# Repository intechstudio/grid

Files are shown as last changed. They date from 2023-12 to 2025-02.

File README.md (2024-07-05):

# Open-Source Hardware [USE THE PAGE ON MASTER BRANCH!]
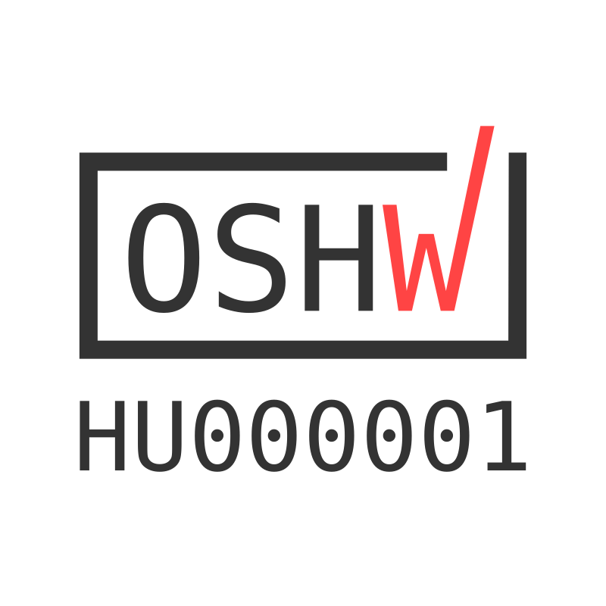
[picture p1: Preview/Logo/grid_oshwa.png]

https://certification.oshwa.org/hu000001.html

Licence: GPL3

# Mechanical components

| Component | Part number | Type | Preview | Links |
|---|---|---|---|---|
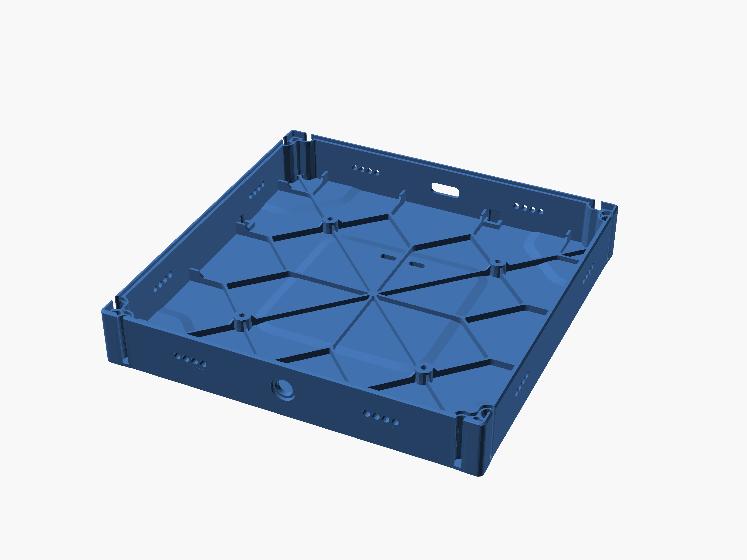
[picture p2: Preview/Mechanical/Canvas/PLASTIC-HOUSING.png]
| Lower housing | PLASTIC-HOUSING | Fabricated |  | [[Model tree]](CANVAS.md) |
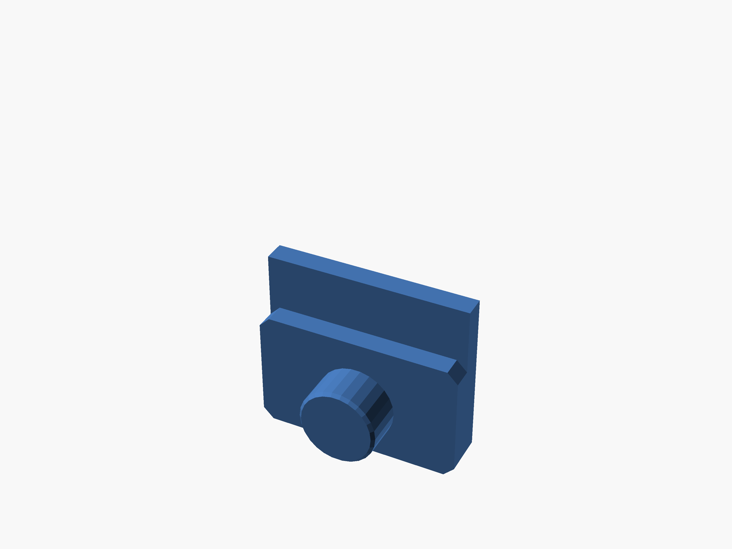
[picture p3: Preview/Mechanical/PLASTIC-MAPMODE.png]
| Mapmode button | PLASTIC-MAPMODE | Fabricated |  | [[step]](Preview/Mechanical/PLASTIC-MAPMODE.step) [[stl]](Preview/Mechanical/PLASTIC-MAPMODE.stl) | 
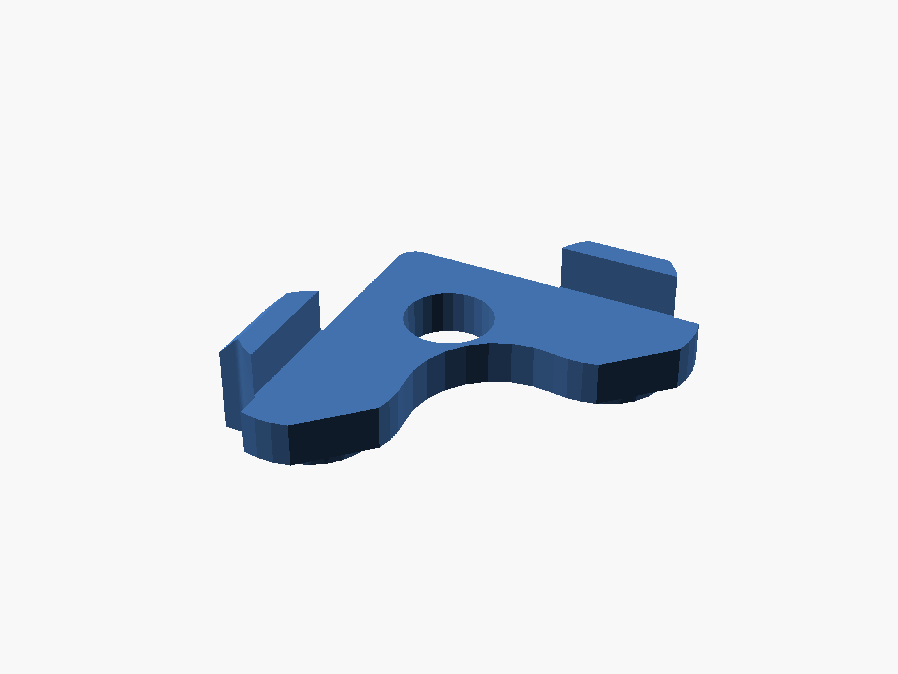
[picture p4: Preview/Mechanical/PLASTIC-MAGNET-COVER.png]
| Magnet cover | PLASTIC-MAGNET-COVER | Fabricated |  | [[step]](Preview/Mechanical/PLASTIC-MAPMODE.step) [[stl]](Preview/Mechanical/PLASTIC-MAGNET-COVER.stl) |  
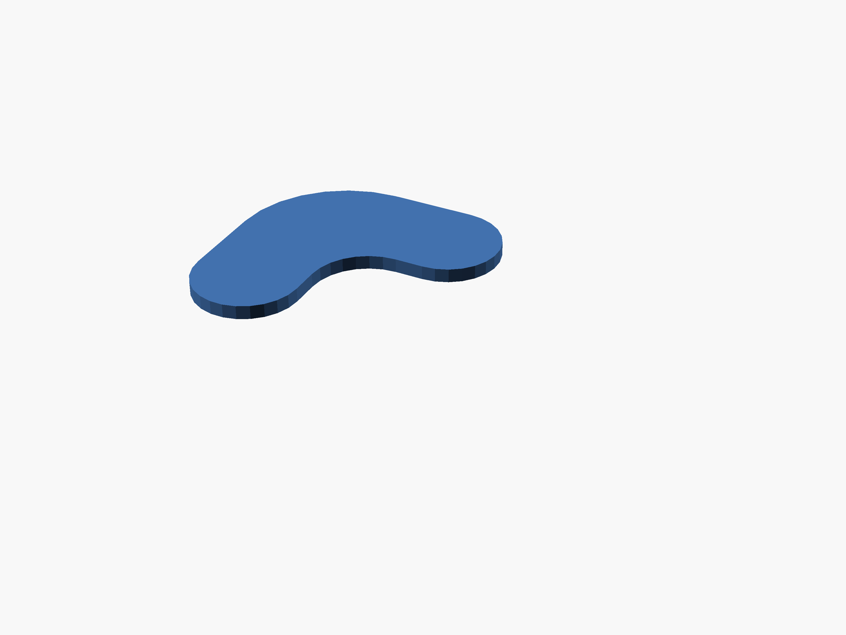
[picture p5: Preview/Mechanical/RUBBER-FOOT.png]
| Rubber foot | RUBBER-FOOT | Fabricated |  | [[step]](Preview/Mechanical/RUBBER-FOOT.step) [[stl]](Preview/Mechanical/RUBBER-FOOT.stl) [[pdf]](Preview/Mechanical/RUBBER-FOOT_Drawing.pdf) |
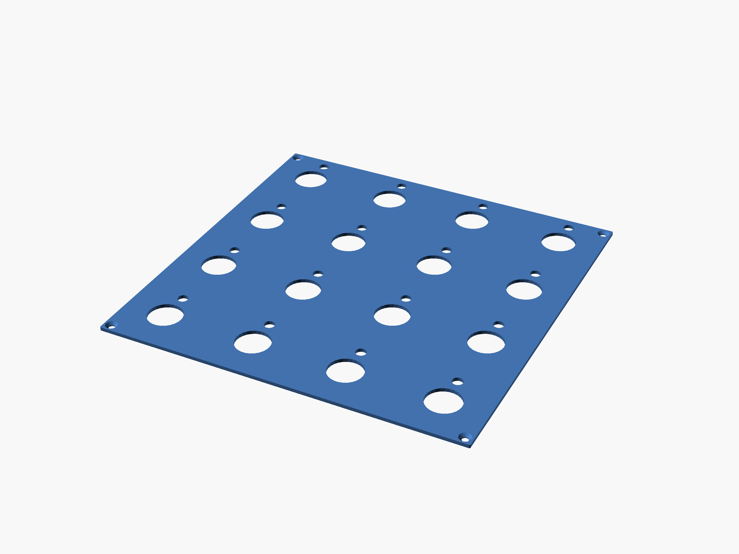
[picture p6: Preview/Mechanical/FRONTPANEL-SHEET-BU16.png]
| Frontpanel BU16 | FRONTPANEL-SHEET-BU16 | Fabricated |  | [[step]](Preview/Mechanical/FRONTPANEL-SHEET-BU16.step) [[stl]](Preview/Mechanical/FRONTPANEL-SHEET-BU16.stl) [[pdf]](Preview/Mechanical/BU16_Drawing.pdf) |
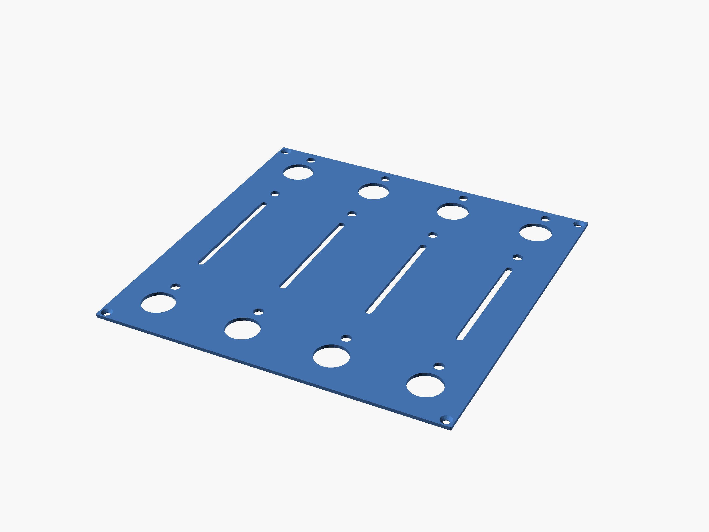
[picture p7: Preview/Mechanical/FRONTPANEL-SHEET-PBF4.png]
| Frontpanel PBF4 | FRONTPANEL-SHEET-PBF4 | Fabricated |  | [[step]](Preview/Mechanical/FRONTPANEL-SHEET-PBF4.step) [[stl]](Preview/Mechanical/FRONTPANEL-SHEET-PBF4.stl) [[pdf]](Preview/Mechanical/PBF4_Drawing.pdf) |
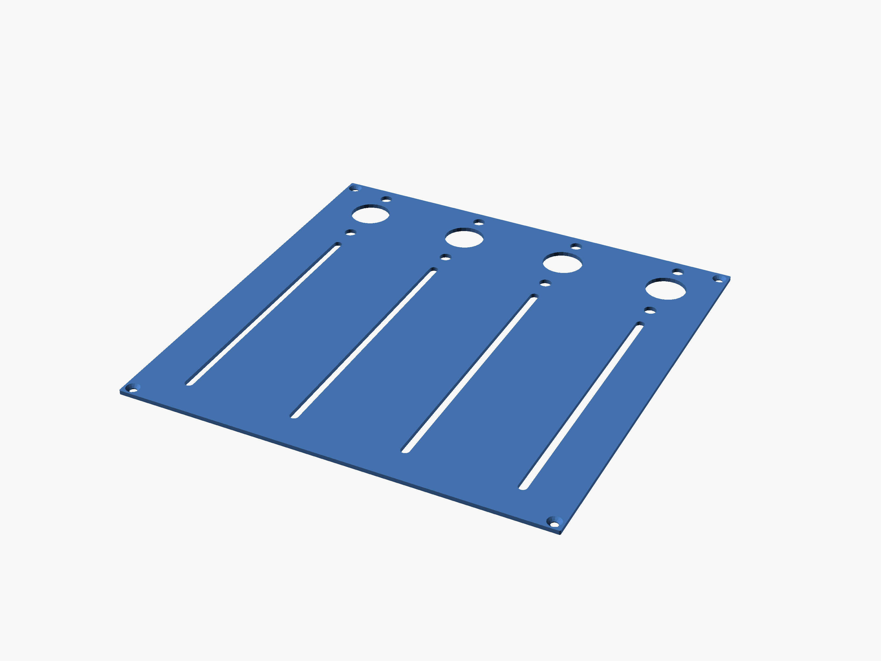
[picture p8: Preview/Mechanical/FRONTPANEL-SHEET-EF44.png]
| Frontpanel EF44 | FRONTPANEL-SHEET-EF44 | Fabricated |  | [[step]](Preview/Mechanical/FRONTPANEL-SHEET-EF44.step) [[stl]](Preview/Mechanical/FRONTPANEL-SHEET-EF44.stl) [[pdf]](Preview/Mechanical/EF44_Drawing.pdf) |
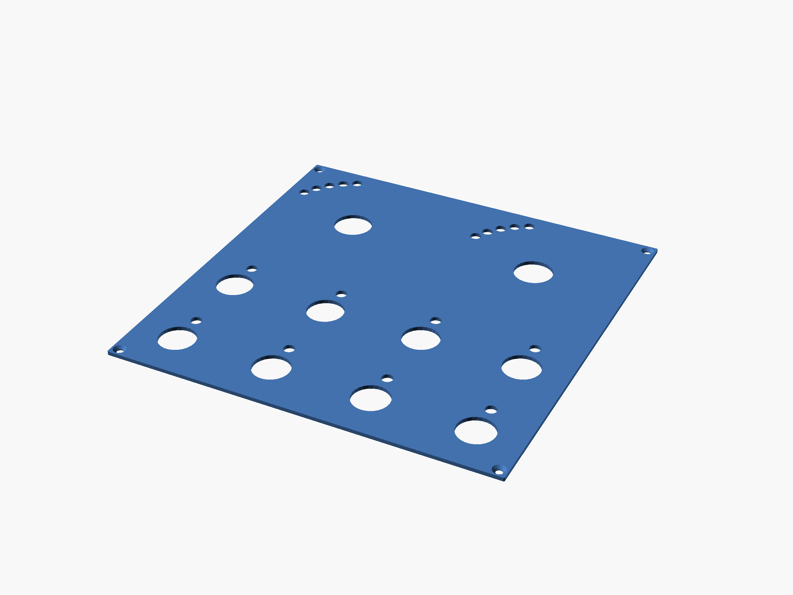
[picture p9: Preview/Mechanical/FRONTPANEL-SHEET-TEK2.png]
| Frontpanel TEK2 | FRONTPANEL-SHEET-TEK2 | Fabricated |  | [[step]](Preview/Mechanical/FRONTPANEL-SHEET-TEK2.step) [[stl]](Preview/Mechanical/FRONTPANEL-SHEET-TEK2.stl) [[pdf]](Preview/Mechanical/TEK2_Drawing.pdf) |
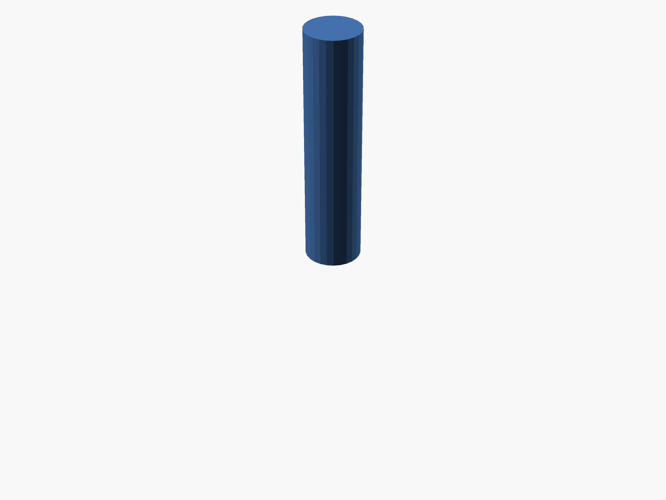
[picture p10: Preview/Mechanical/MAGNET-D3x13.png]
| D3x13mm N52 neodymium | MAGNET-D3x13 | Fabricated |  | [[step]](Preview/Mechanical/MAGNET-D3x13.step) [[stl]](Preview/Mechanical/MAGNET-D3x13.stl) [[pdf]](Preview/Mechanical/MAGNET-D3x13_Drawing.pdf) |
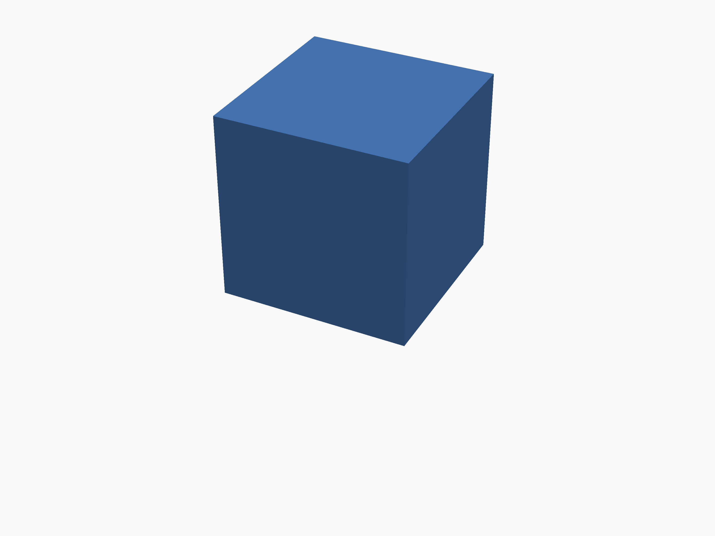
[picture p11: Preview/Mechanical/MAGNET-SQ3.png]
| 3x3x3mm N52 neodymium | MAGNET-SQ3 | Fabricated |  | [[step]](Preview/Mechanical/MAGNET-SQ3.step) [[stl]](Preview/Mechanical/MAGNET-SQ3.stl) [[pdf]](Preview/Mechanical/MAGNET-SQ3_Drawing.pdf) |
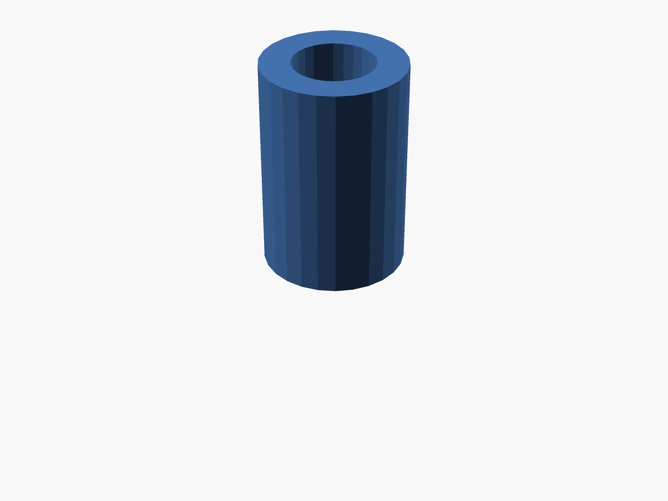
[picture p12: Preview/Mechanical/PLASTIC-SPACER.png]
| Crown | PLASTIC-SPACER | Fabricated |  | [[step]](Preview/Mechanical/PLASTIC-SPACER.step) [[stl]](Preview/Mechanical/PLASTIC-SPACER.stl) [[pdf]](Preview/Mechanical/PLASTIC-SPACER_Drawing.pdf) |
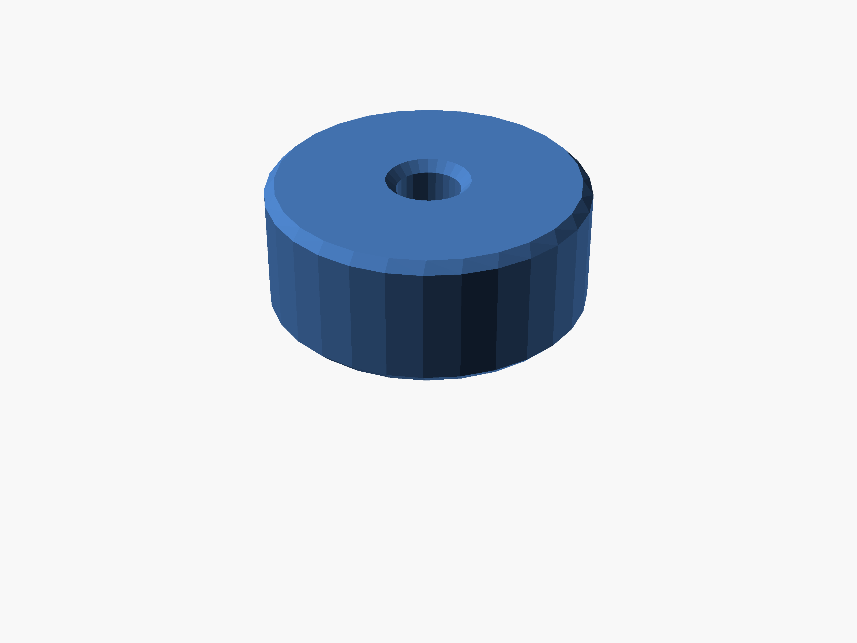
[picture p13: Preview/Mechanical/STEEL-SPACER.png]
| Crown | STEEL-SPACER | Fabricated |  | [[step]](Preview/Mechanical/STEEL-SPACER.step) [[stl]](Preview/Mechanical/STEEL-SPACER.stl) [[pdf]](Preview/Mechanical/STEEL-SPACER_Drawing.pdf) |
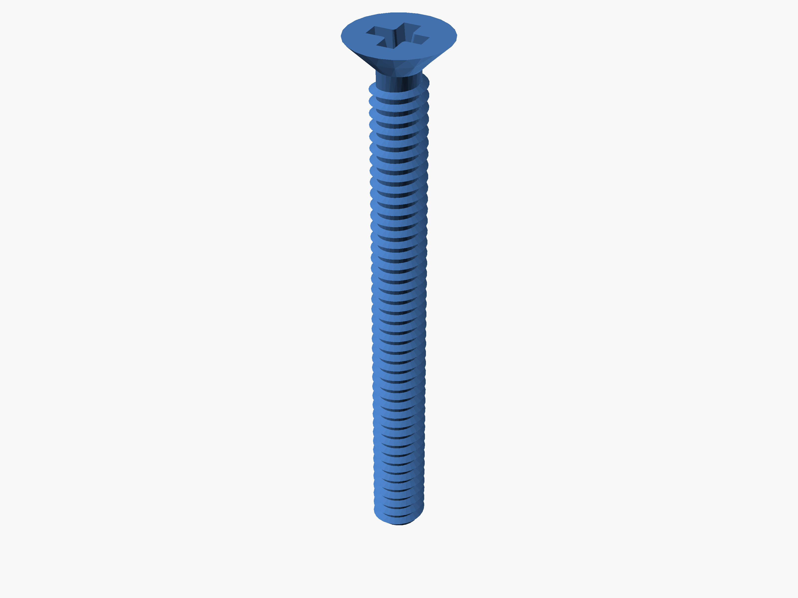
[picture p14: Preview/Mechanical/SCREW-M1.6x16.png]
| Metric corner screw | SCREW-M1.6x16 | Purchased  |  | [[step]](Preview/Mechanical/SCREW-M1.6x16.step) [[stl]](Preview/Mechanical/SCREW-M1.6x16.stl) |
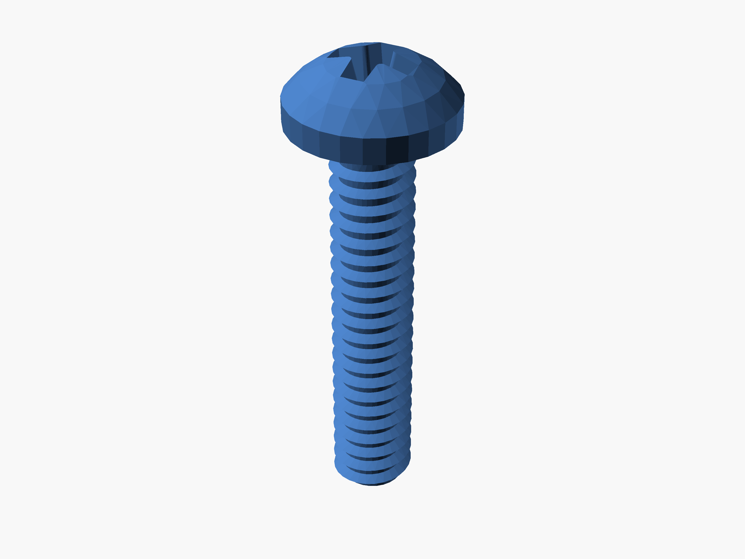
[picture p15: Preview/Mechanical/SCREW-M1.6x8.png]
| Metric PCB screw | SCREW-M1.6x8 | Purchased  |  | [[step]](Preview/Mechanical/SCREW-M1.6x8.step) [[stl]](Preview/Mechanical/SCREW-M1.6x8.stl)|
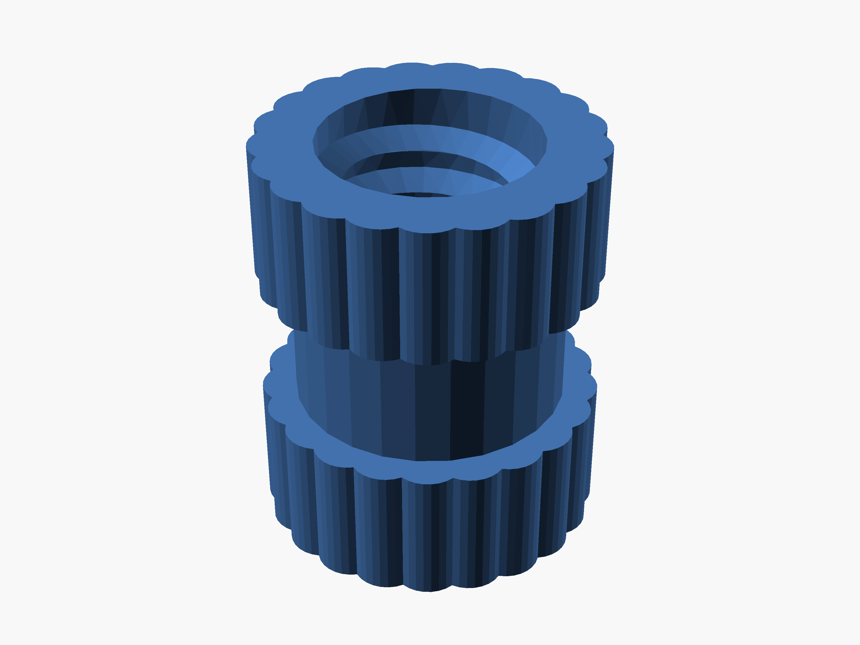
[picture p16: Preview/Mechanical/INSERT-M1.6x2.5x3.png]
| Brass threaded insert 3mm | INSERT-M1.6x2.5x3 | Purchased  |  | [[step]](Preview/Mechanical/INSERT-M1.6x2.5x3.step) [[stl]](Preview/Mechanical/INSERT-M1.6x2.5x3.stl) |
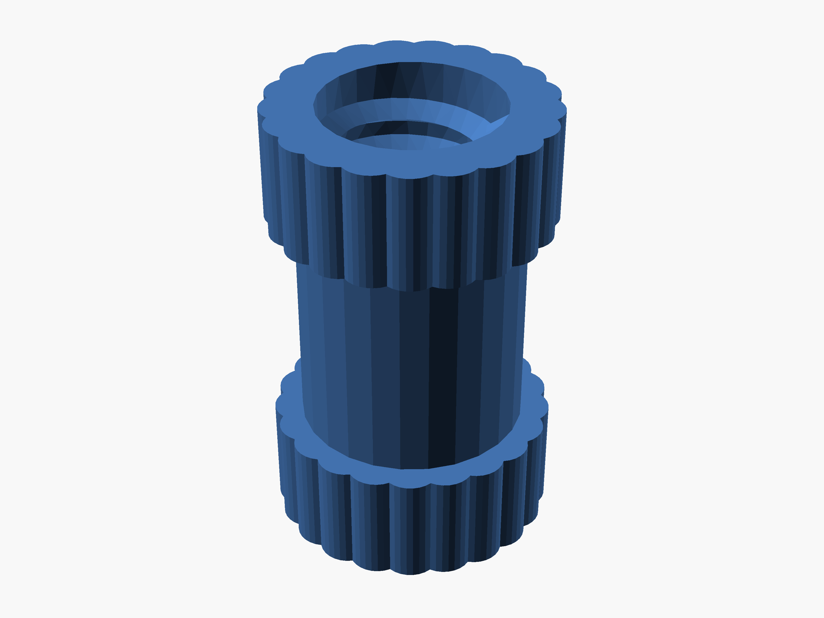
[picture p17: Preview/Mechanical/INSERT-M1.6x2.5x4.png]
| Brass threaded insert 4mm | INSERT-M1.6x2.5x4 | Purchased  |  | [[step]](Preview/Mechanical/INSERT-M1.6x2.5x4.step) [[stl]](Preview/Mechanical/INSERT-M1.6x2.5x4.stl) |
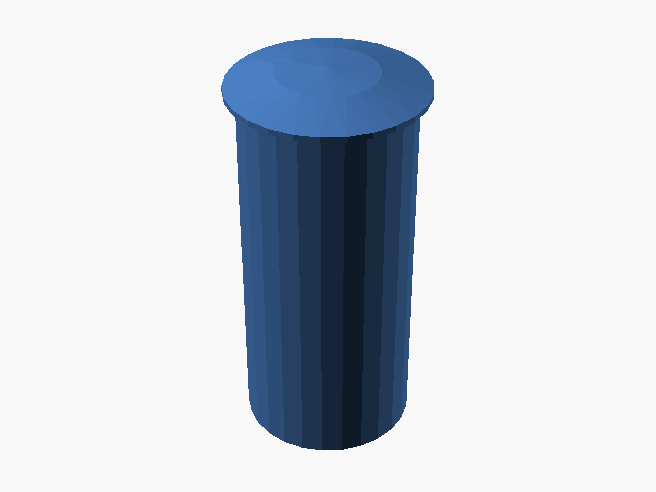
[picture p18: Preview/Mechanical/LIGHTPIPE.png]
| Lightpipe | PLASTIC-LIGHTPIPE | Purchased  |  | [[step]](Preview/Mechanical/LIGHTPIPE.step) [[stl]](Preview/Mechanical/LIGHTPIPE.stl)  |
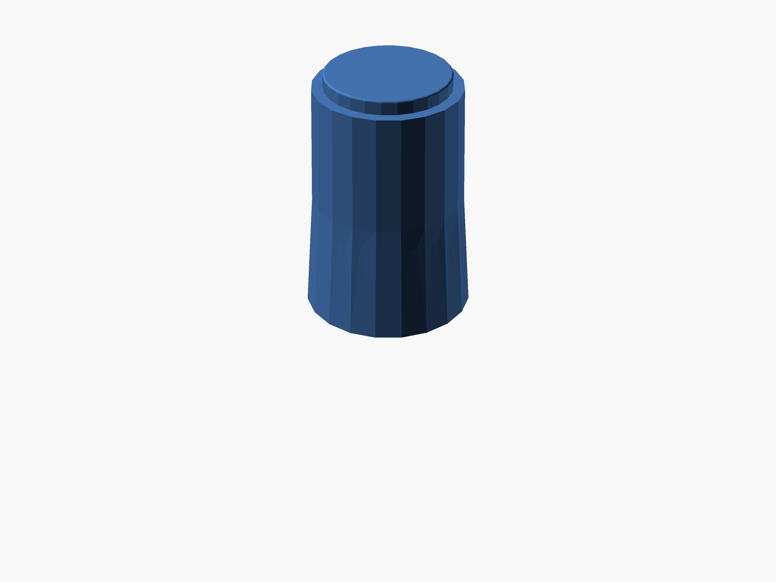
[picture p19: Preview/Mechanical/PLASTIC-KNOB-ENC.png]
| Encoder Knob Injection | PLASTIC-KNOB-ENC | Fabricated |  | [[step]](Preview/Mechanical/PLASTIC-KNOB-ENC.step) [[stl]](Preview/Mechanical/PLASTIC-KNOB-ENC.stl) [[pdf]](Preview/Mechanical/PLASTIC-KNOB-ENC_Drawing.pdf) |
| Potmeter Knob Injection | PLASTIC-KNOB-POT | Fabricated |  | [[step]](Preview/Mechanical/PLASTIC-KNOB-POT.step) [[stl]](Preview/Mechanical/PLASTIC-KNOB-POT.stl) [[pdf]](Preview/Mechanical/PLASTIC-KNOB-POT_Drawing.pdf) |
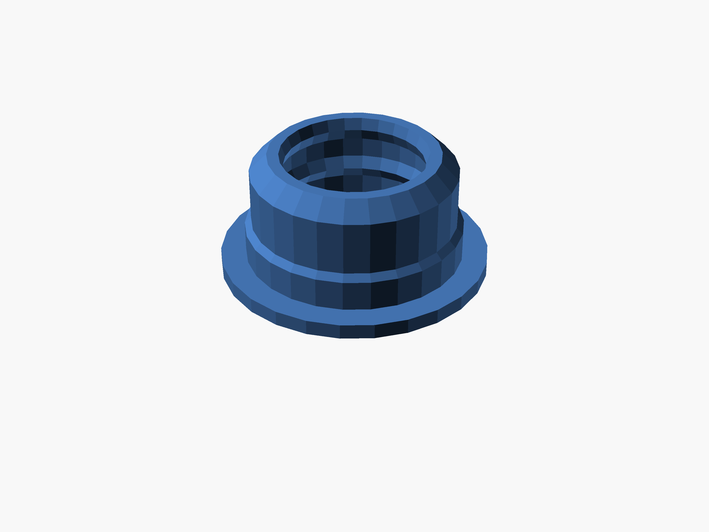
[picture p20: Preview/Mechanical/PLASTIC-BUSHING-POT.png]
| Potmeter Bushing | PLASTIC-BUSHING-POT  | Fabricated |  | [[step]](Preview/Mechanical/PLASTIC-BUSHING-POT.step) [[stl]](Preview/Mechanical/PLASTIC-BUSHING-POT.stl) [[pdf]](Preview/Mechanical/PLASTIC-BUSHING-POT_Drawing.pdf) |
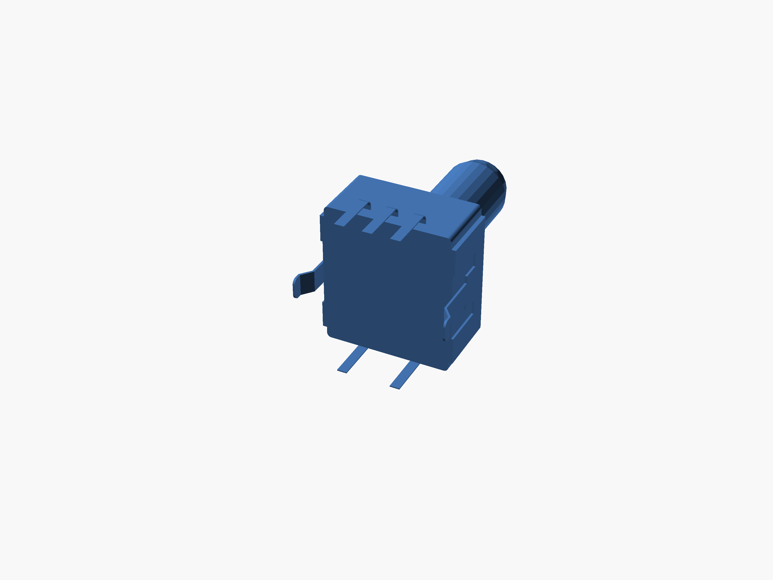
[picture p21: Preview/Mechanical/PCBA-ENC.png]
| Encoder | PCBA-ENC | Purchased  |  | [[step]](Preview/Mechanical/PCBA-ENC.step) [[stl]](Preview/Mechanical/PCBA-ENC.stl) [[pdf]](Preview/Mechanical/PCBA-ENC.pdf) |
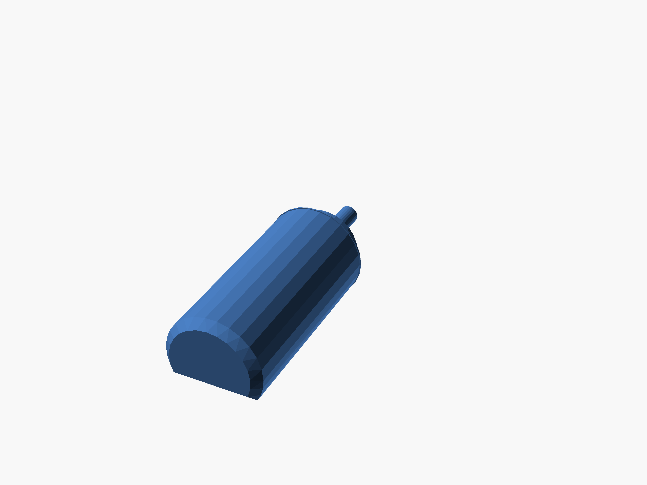
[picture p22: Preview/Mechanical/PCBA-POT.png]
| Potmeter | PCBA-POT | Purchased  |  | [[step]](Preview/Mechanical/PCBA-POT.step) [[stl]](Preview/Mechanical/PCBA-POT.stl) [[pdf]](Preview/Mechanical/PCBA-POT.pdf) |
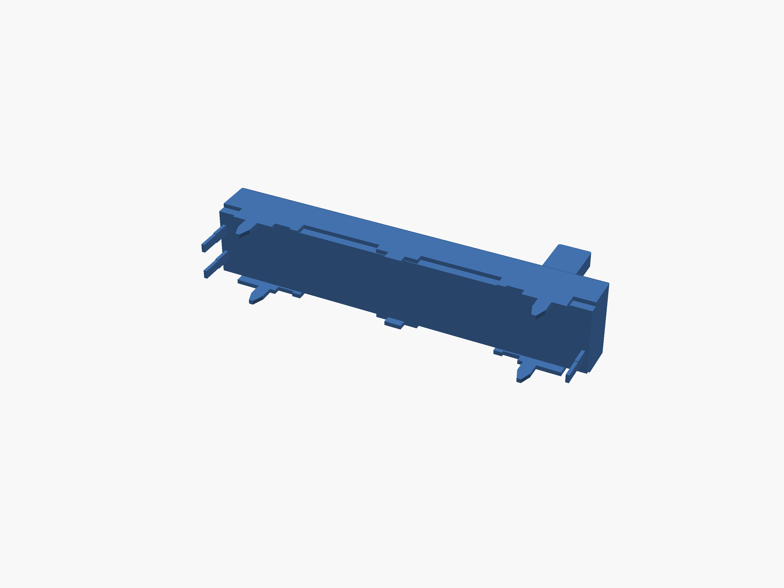
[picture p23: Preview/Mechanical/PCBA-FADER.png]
| Fader | PCBA-FADER | Purchased  |  | [[step]](Preview/Mechanical/PCBA-FADER.step) [[stl]](Preview/Mechanical/PCBA-FADER.stl) [[pdf]](Preview/Mechanical/PCBA-FADER.pdf) |
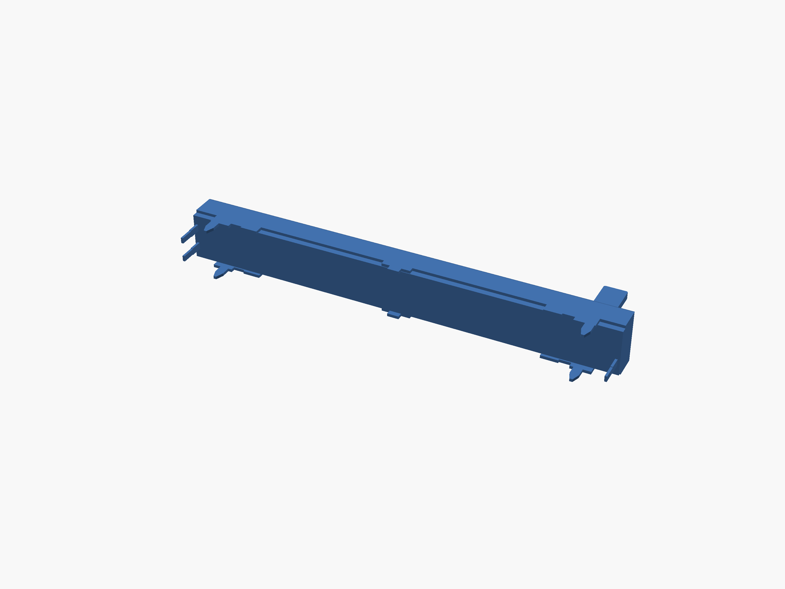
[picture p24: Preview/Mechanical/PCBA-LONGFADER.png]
| Long Fader | PCBA-LONGFADER | Purchased  |  | [[step]](Preview/Mechanical/PCBA-LONGFADER.step) [[stl]](Preview/Mechanical/PCBA-LONGFADER.stl) [[pdf]](Preview/Mechanical/PCBA-LONGFADER.pdf) |
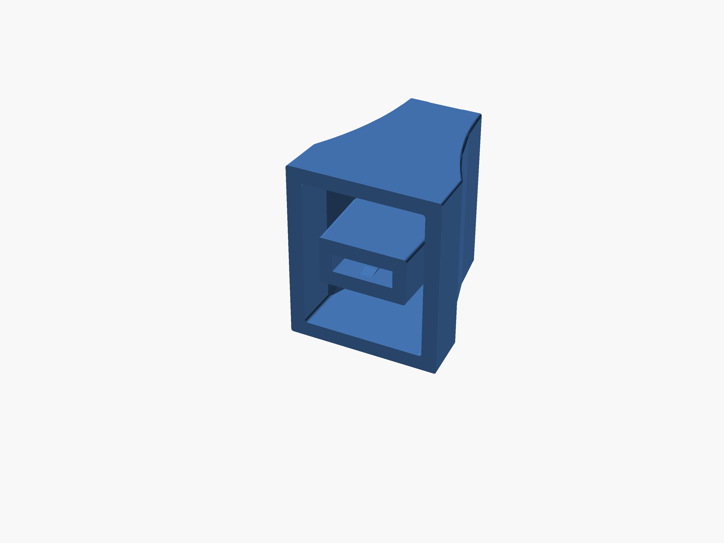
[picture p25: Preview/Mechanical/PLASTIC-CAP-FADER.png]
| Fader Cap | PLASTIC-CAP-FADER | Purchased  |  | [[step]](Preview/Mechanical/PLASTIC-CAP-FADER.step) [[stl]](Preview/Mechanical/PLASTIC-CAP-FADER.stl) |
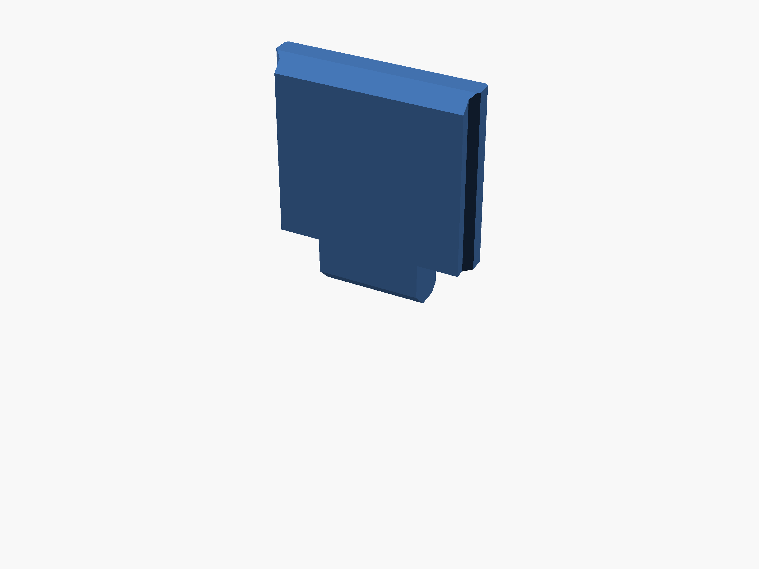
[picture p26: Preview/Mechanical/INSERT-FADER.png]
| Fader Insert | INSERT-FADER | Fabricated  |  | [[step]](Preview/Mechanical/INSERT-FADER.step) [[stl]](Preview/Mechanical/INSERT-FADER.stl) |
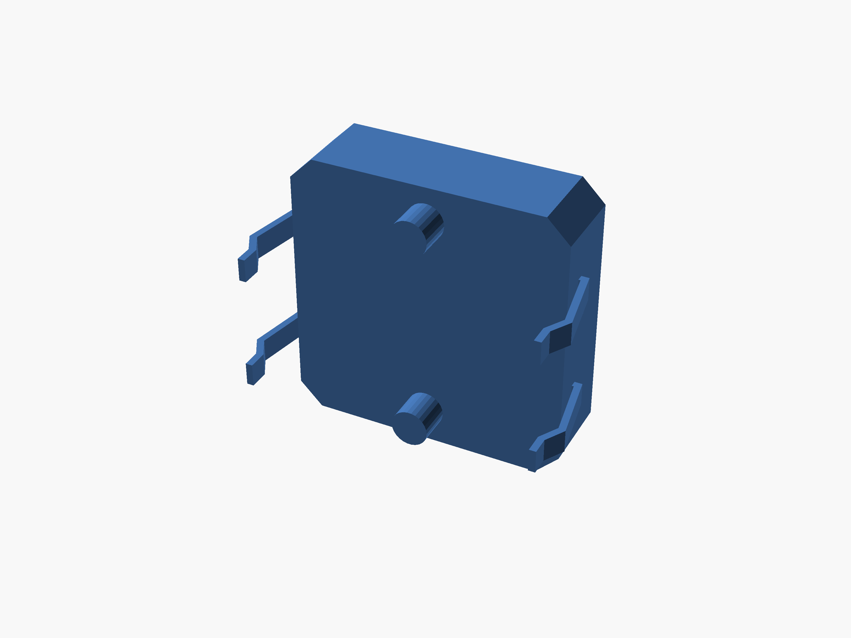
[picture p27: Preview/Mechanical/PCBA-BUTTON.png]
| Button | PCBA-BUTTON | Purchased  |  | [[step]](Preview/Mechanical/PCBA-BUTTON.step) [[stl]](Preview/Mechanical/PCBA-BUTTON.stl) |
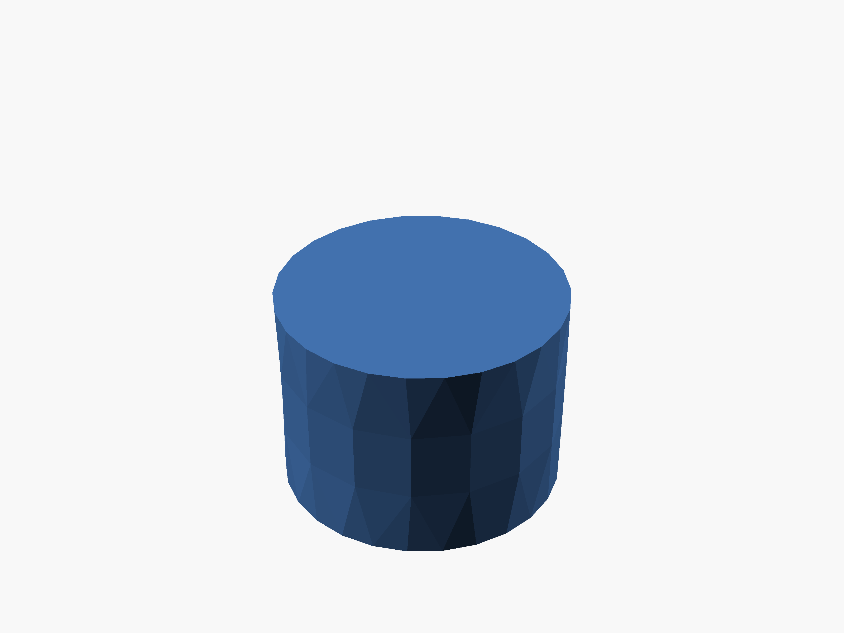
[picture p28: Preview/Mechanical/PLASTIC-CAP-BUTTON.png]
| Button Cap | PLASTIC-CAP-BUTTON | Purchased  |  | [[step]](Preview/Mechanical/PLASTIC-CAP-BUTTON.step) [[stl]](Preview/Mechanical/PLASTIC-CAP-BUTTON.stl) |

# TEK2 specific components
| Component | Part number | Type | Preview | Links |
|---|---|---|---|---|
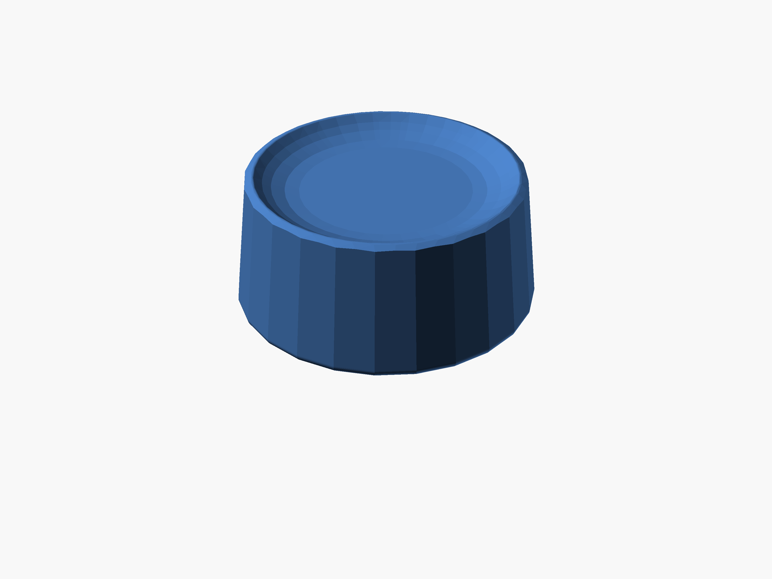
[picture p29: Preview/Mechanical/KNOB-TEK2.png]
| Knob TEK2 | KNOB-TEK2 | Fabricated |  | [[step]](Preview/Mechanical/KNOB-TEK2.step) [[stl]](Preview/Mechanical/KNOB-TEK2.stl) [[pdf]](Preview/Mechanical/KNOB-TEK2_Drawing.pdf) |
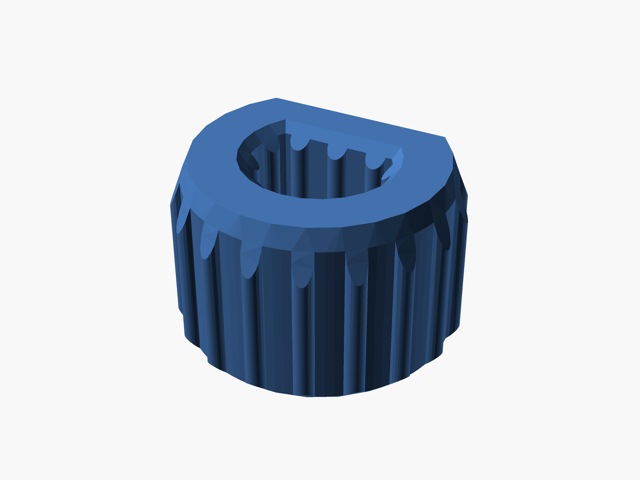
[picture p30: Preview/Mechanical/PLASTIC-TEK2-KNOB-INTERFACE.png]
| Knob interface TEK2 | PLASTIC-TEK2-KNOB-INTERFACE | Fabricated |  | [[step]](Preview/Mechanical/PLASTIC-TEK2-KNOB-INTERFACE.step) [[stl]](Preview/Mechanical/PLASTIC-TEK2-KNOB-INTERFACE.stl) |
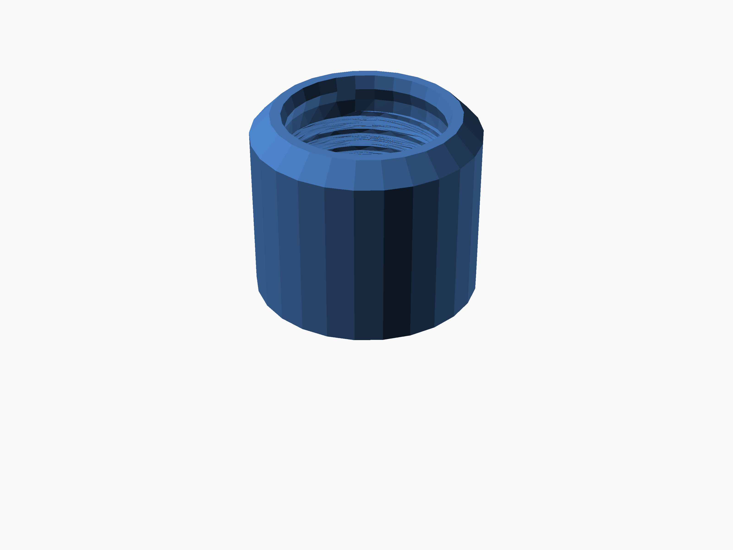
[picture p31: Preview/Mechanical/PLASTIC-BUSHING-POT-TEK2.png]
| Potmeter Bushing TEK2 | PLASTIC-BUSHING-POT-TEK2 | Fabricated |  | [[step]](Preview/Mechanical/PLASTIC-BUSHING-POT-TEK2.step) [[stl]](Preview/Mechanical/PLASTIC-BUSHING-POT-TEK2.stl) [[pdf]](Preview/Mechanical/PLASTIC-BUSHING-POT-TEK2_Drawing.pdf) |
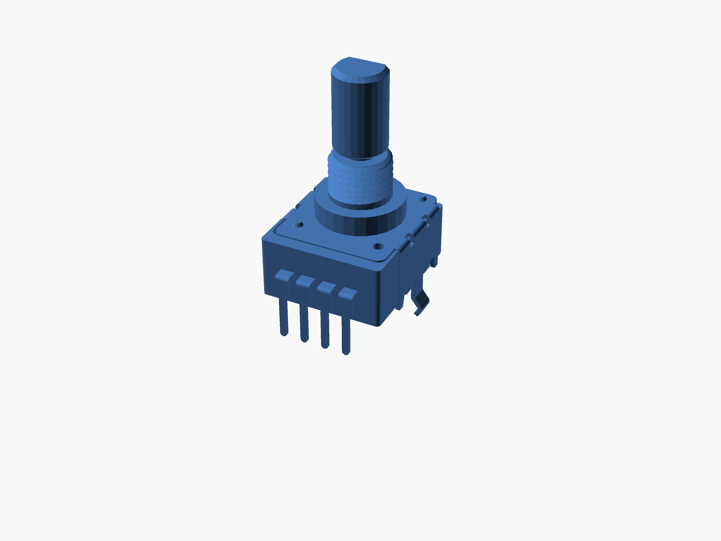
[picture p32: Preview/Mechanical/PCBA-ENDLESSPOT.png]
| Endless potentiometer | PCBA-ENDLESSPOT | Purchased  |  | [[step]](Preview/Mechanical/PCBA-ENDLESSPOT.step) [[stl]](Preview/Mechanical/PCBA-ENDLESSPOT.stl) [[pdf]](Preview/Mechanical/PCBA-ENDLESSPOT.pdf) |
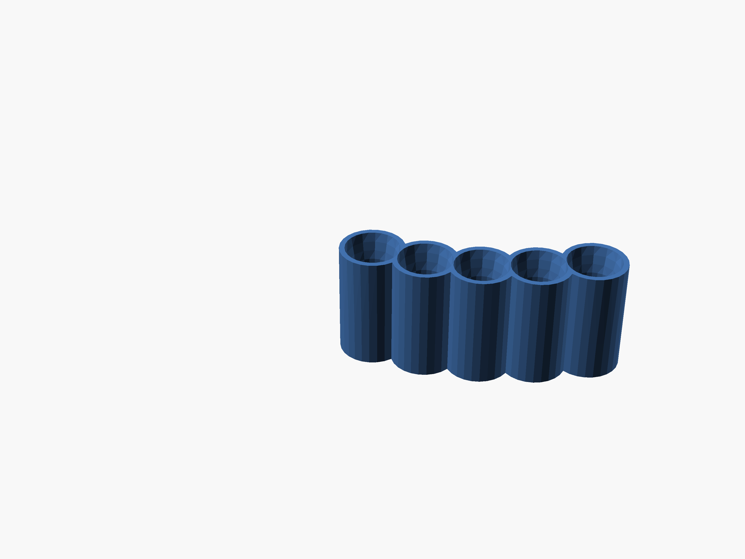
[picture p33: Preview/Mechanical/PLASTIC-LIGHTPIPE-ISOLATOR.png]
| TEK2 Lightpipe isolator | PLASTIC-LIGHTPIPE-ISOLATOR | Fabricated |  | [[step]](Preview/Mechanical/PLASTIC-LIGHTPIPE-ISOLATOR.step) [[stl]](Preview/Mechanical/PLASTIC-LIGHTPIPE-ISOLATOR.stl) |

# TEK1 specific components
| Component | Part number | Type | Preview | Links |
|---|---|---|---|---|
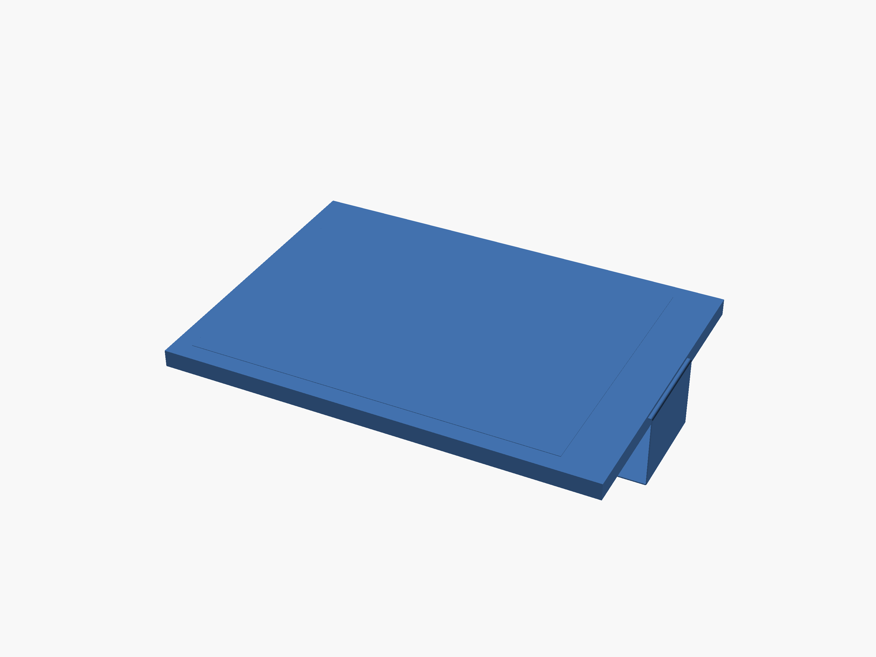
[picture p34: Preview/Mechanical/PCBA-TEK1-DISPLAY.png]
| TEK1 Display | PCBA-TEK1-DISPLAY | Purchased |  | [[step]](Preview/Mechanical/PCBA-TEK1-DISPLAY.step) [[stl]](Preview/Mechanical/PCBA-TEK1-DISPLAY.stl) |
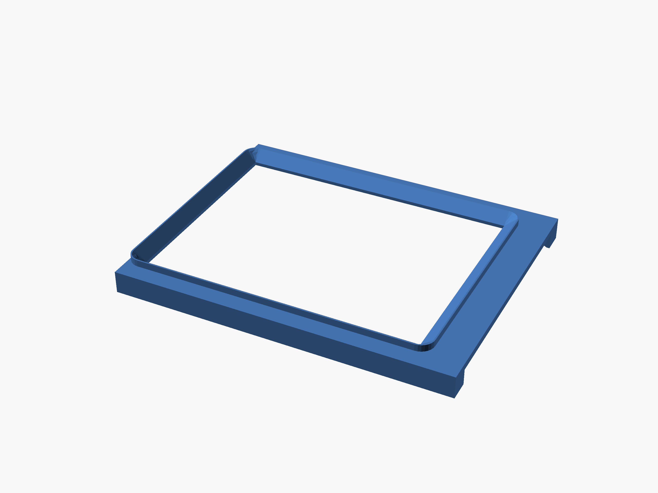
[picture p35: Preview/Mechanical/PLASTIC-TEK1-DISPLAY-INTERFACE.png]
| TEK1 Display interface | PLASTIC-TEK1-DISPLAY-INTERFACE | Fabricated |  | [[step]](Preview/Mechanical/PLASTIC-TEK1-DISPLAY-INTERFACE.step) [[stl]](Preview/Mechanical/PLASTIC-TEK1-DISPLAY-INTERFACE.stl) |
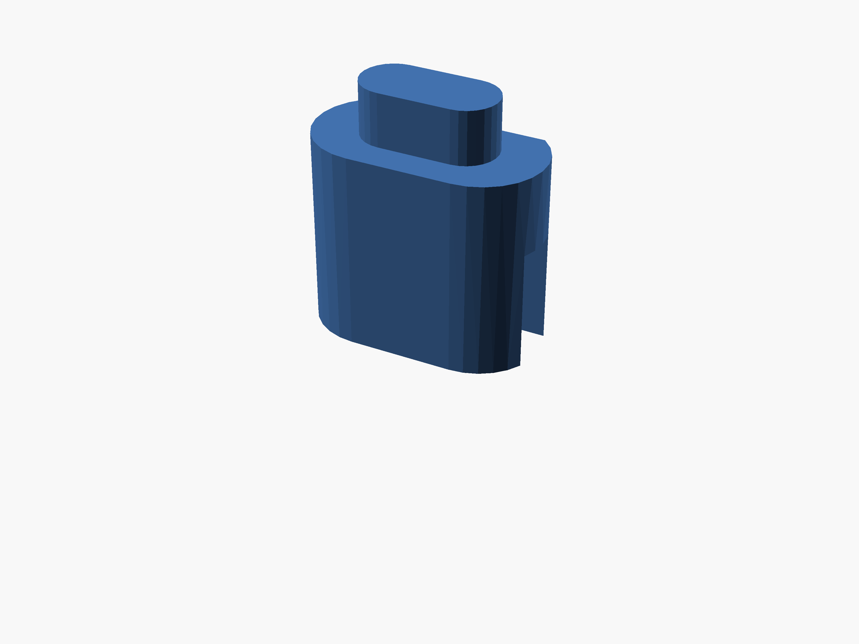
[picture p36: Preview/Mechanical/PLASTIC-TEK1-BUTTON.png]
| TEK1 Button | PLASTIC-TEK1-BUTTON | Fabricated |  | [[step]](Preview/Mechanical/PLASTIC-TEK1-BUTTON.step) [[stl]](Preview/Mechanical/PLASTIC-TEK1-BUTTON.stl) |

## Electrical components

| Component | Part number | Preview | Links |
|---|---|---|---|
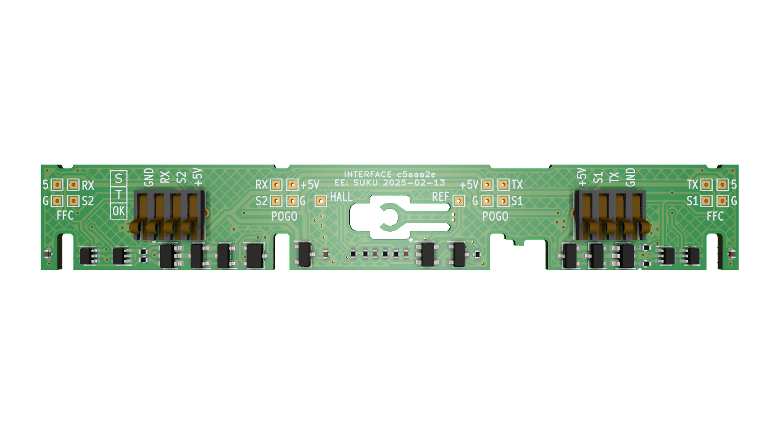
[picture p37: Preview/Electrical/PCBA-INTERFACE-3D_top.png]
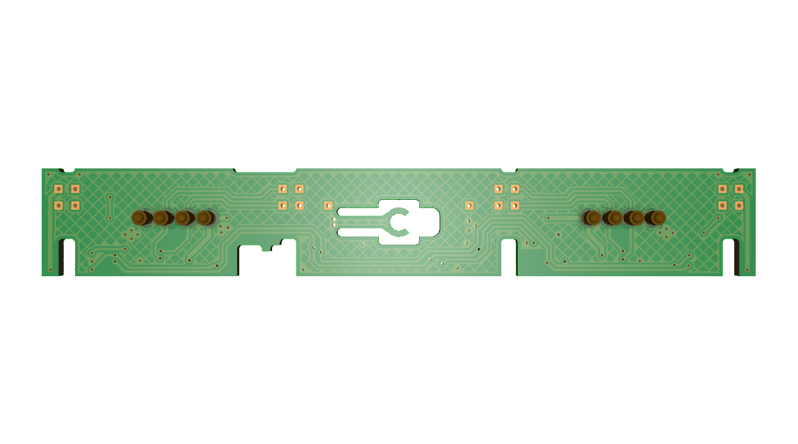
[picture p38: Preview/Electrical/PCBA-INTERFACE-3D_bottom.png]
| Interfaceboard | PCBA-INTERFACE |   | [[Schematic]](Preview/Electrical/PCBA-INTERFACE_Schematic.pdf) [[STEP]](Preview/Electrical/PCBA-INTERFACE-3D.step?raw=true) [[Gerber]](Preview/Electrical/mfg/PCBA-INTERFACE-gerber.zip?raw=true)  [[PCB3D]](Preview/Electrical/PCBA-INTERFACE-blender_export.pcb3d?raw=true)  |
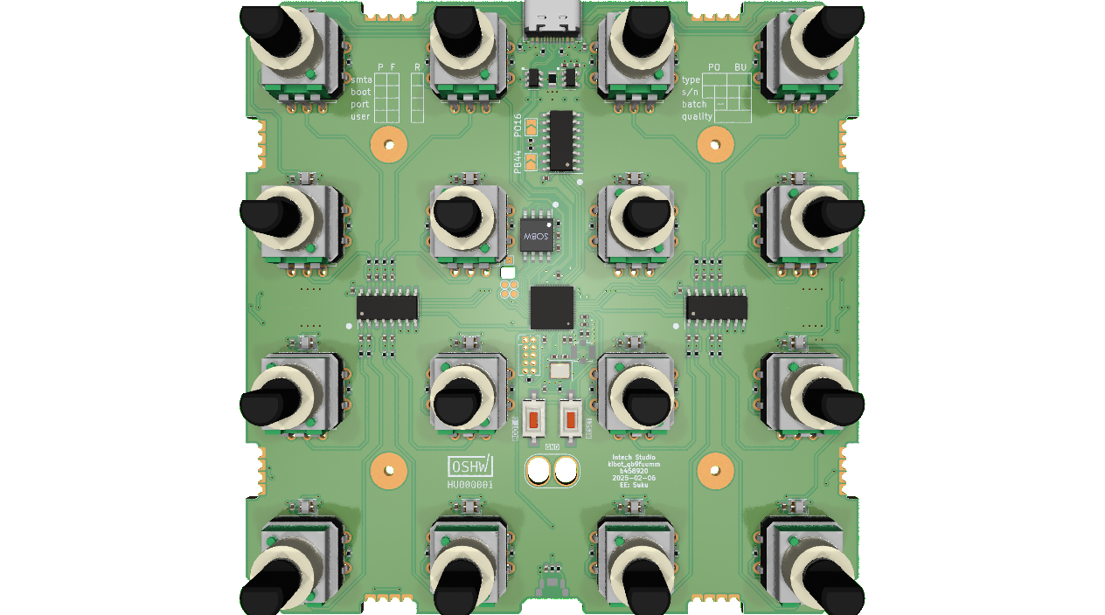
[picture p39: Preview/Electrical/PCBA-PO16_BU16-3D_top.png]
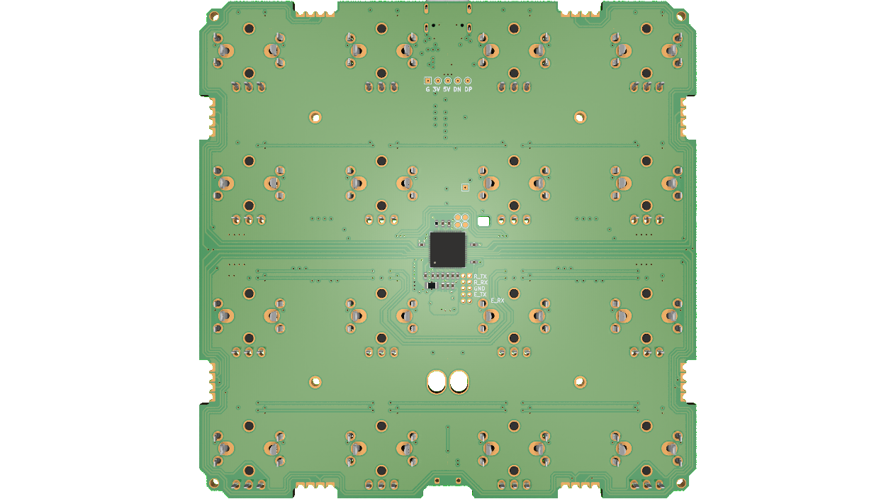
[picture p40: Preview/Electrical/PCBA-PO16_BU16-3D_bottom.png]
| PO16/BU16 Motherboard | PCBA-PO16_BU16 |    | [[schematic]](Preview/Electrical/PCBA-PO16_BU16_Schematic.pdf) [[STEP]](Preview/Electrical/PCBA-PO16_BU16-3D.step?raw=true)  [[PCB3D]](Preview/Electrical/PCBA-PO16_BU16-blender_export.pcb3d?raw=true)  |
| PBF4 Motherboard | PCBA-PBF4 |    | [[schematic]](Preview/Electrical/PCBA-PBF4_Schematic.pdf) [[STEP]](Preview/Electrical/PCBA-PBF4-3D.step?raw=true) [[PCB3D]](Preview/Electrical/PCBA-PBF4-blender_export.pcb3d?raw=true)  |
| EN16 Motherboard | PCBA-EN16 |    | [[schematic]](Preview/Electrical/PCBA-EN16_Schematic.pdf) [[STEP]](Preview/Electrical/PCBA-EN16-3D.step?raw=true) [[PCB3D]](Preview/Electrical/PCBA-EN16-blender_export.pcb3d?raw=true) |
| EF44 Motherboard | PCBA-EF44 |    | [[schematic]](Preview/Electrical/PCBA-EF44_Schematic.pdf) [[STEP]](Preview/Electrical/PCBA-EF44-3D.step?raw=true) [[PCB3D]](Preview/Electrical/PCBA-EF44-blender_export.pcb3d?raw=true) |
| TEK2 Motherboard | PCBA-TEK2 |    | [[schematic]](Preview/Electrical/PCBA-TEK2_Schematic.pdf) [[STEP]](Preview/Electrical/PCBA-TEK2-3D.step?raw=true) [[PCB3D]](Preview/Electrical/PCBA-TEK2-blender_export.pcb3d?raw=true) |
| TEK1 Motherboard | PCBA-TEK1 |    | [[schematic]](Preview/Electrical/PCBA-TEK1_Schematic.pdf) [[STEP]](Preview/Electrical/PCBA-TEK1-3D.step?raw=true) [[PCB3D]](Preview/Electrical/PCBA-TEK1-blender_export.pcb3d?raw=true) |
| TEK1 BNT GROUP | PCBA-TEK1-BTNGROUP |    | [[schematic]](Preview/Electrical/PCBA-TEK1-BTNGROUP_Schematic.pdf) [[STEP]](Preview/Electrical/PCBA-TEK1-BTNGROUP-3D.step?raw=true) [[PCB3D]](Preview/Electrical/PCBA-TEK1-BTNGROUP-blender_export.pcb3d?raw=true) |

# Desktop Tools Used
- FreeCAD
- KiCAD
# Command-Line Tools Used
- PytonOCC
- OpenSCAD
- KiBOT

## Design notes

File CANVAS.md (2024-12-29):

## PLASTIC-HOUSING
Lower plastic casing of the project (internally codenamed Canvas)
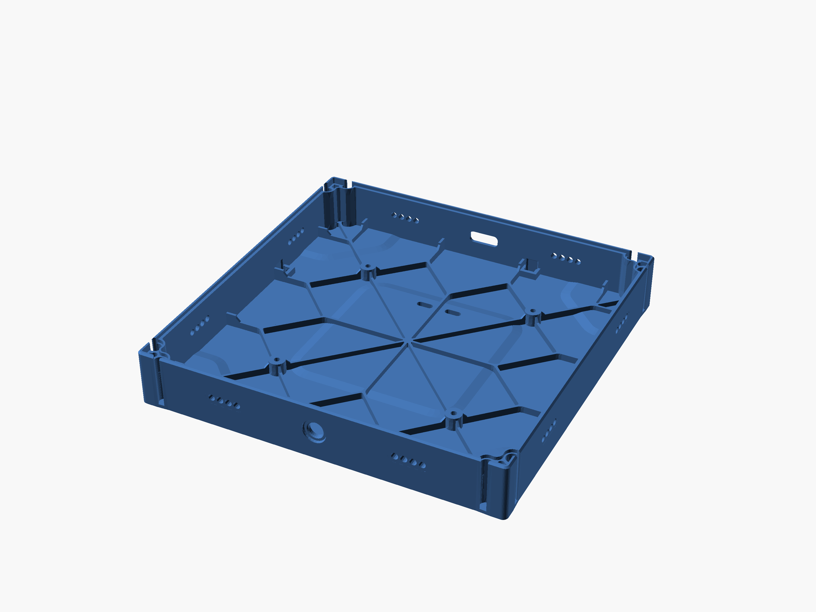
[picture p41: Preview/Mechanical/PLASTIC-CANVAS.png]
Canvas


## Boolian features
Canvas final geometry is formed by subtracting each separately designed feature from a base cube one-by-one.
### [[STL]](Preview/Mechanical/feature_edge_compensation_nominal_drafted.stl) 1. Preview/Mechanical/feature_edge_compensation_nominal_drafted
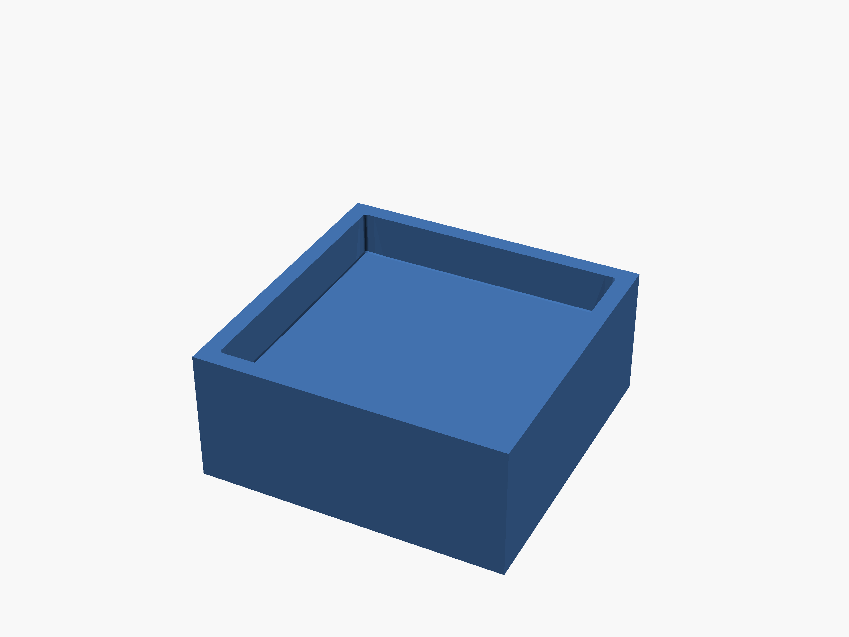
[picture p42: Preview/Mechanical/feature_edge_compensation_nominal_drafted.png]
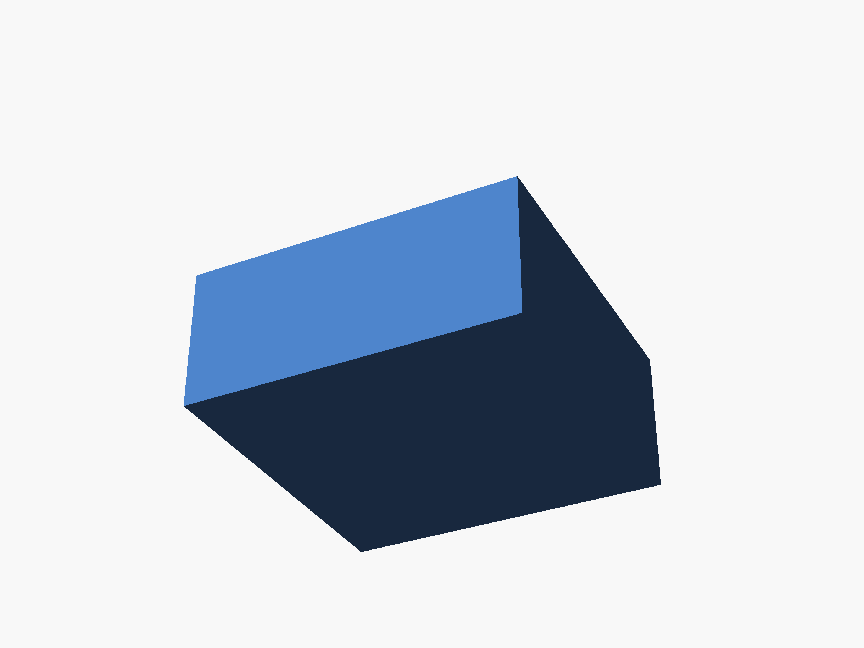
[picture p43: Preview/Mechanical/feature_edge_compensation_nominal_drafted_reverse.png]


### [[STL]](Preview/Mechanical/feature_alignment_bevel_B.stl) 2. Preview/Mechanical/feature_alignment_bevel_B
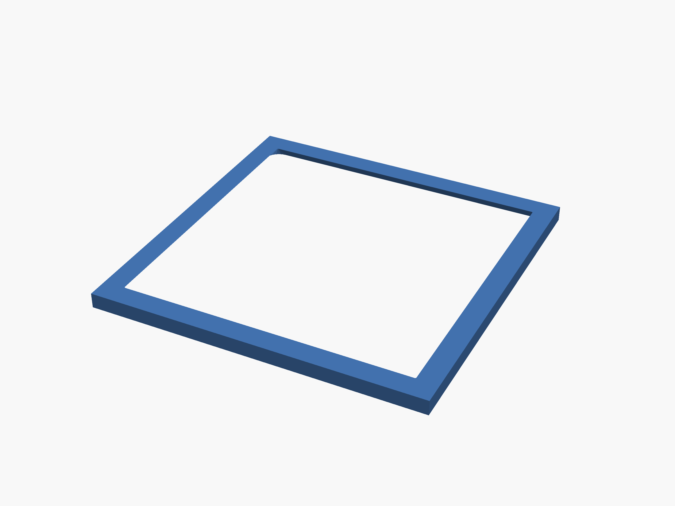
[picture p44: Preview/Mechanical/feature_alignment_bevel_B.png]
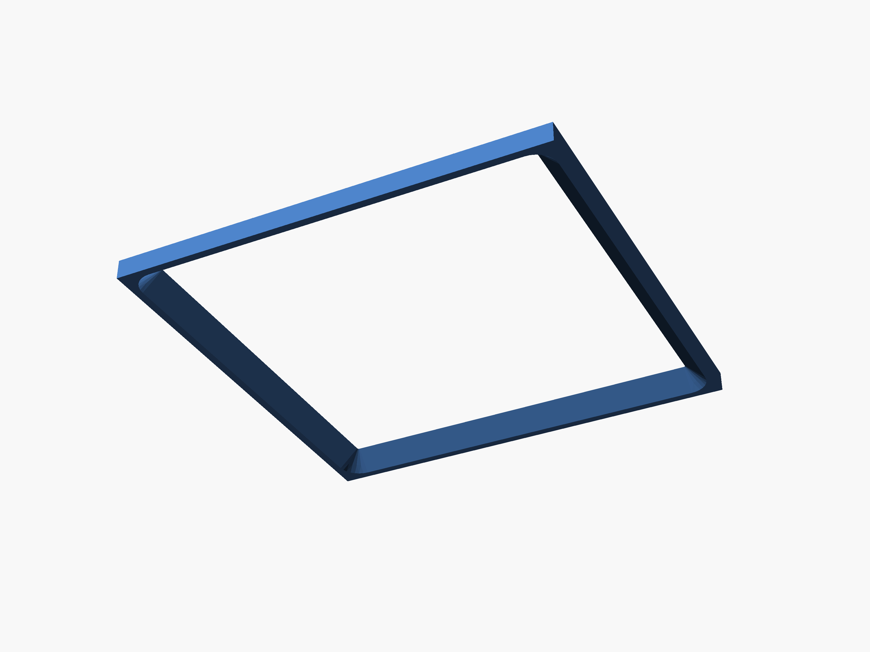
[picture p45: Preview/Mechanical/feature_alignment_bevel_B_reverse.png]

### [[STL]](Preview/Mechanical/feature_usb_hole.stl) 3. Preview/Mechanical/feature_usb_hole
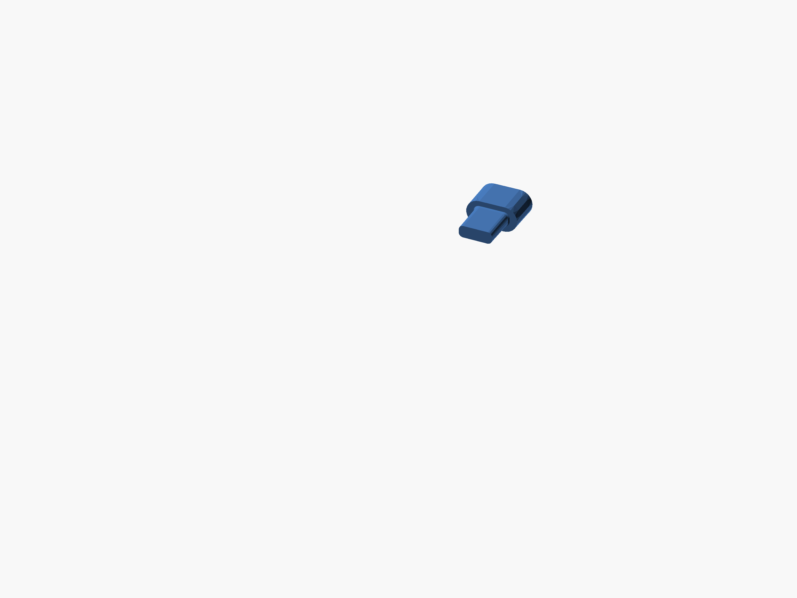
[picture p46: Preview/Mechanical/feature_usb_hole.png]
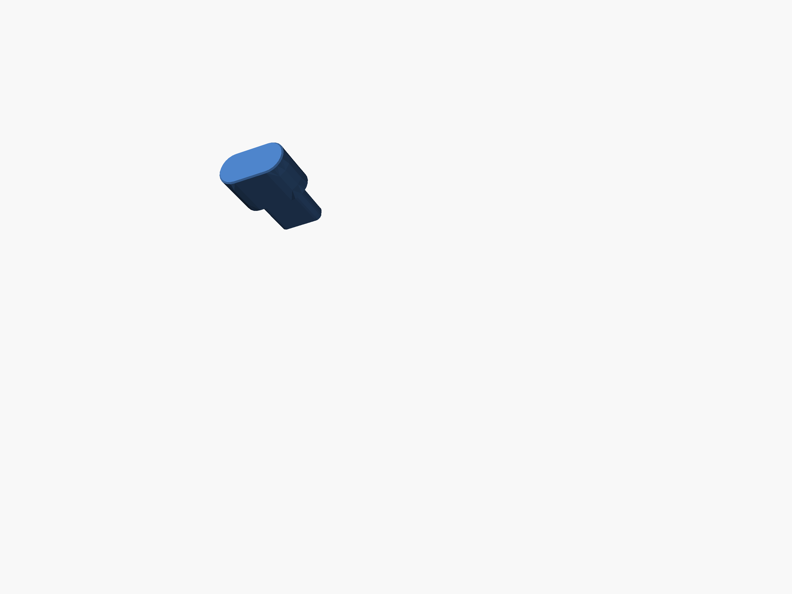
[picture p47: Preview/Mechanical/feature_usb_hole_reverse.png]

### [[STL]](Preview/Mechanical/feature_map_hole.stl) 4. Preview/Mechanical/feature_map_hole
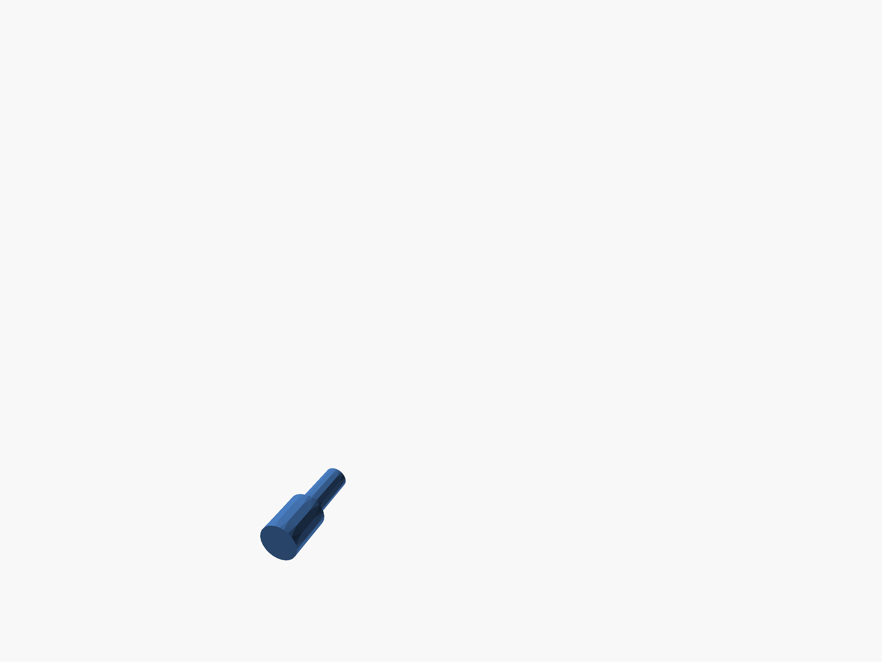
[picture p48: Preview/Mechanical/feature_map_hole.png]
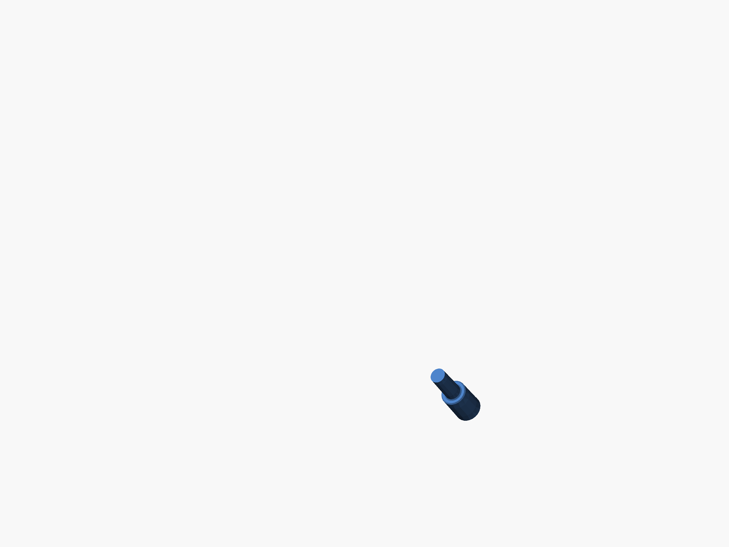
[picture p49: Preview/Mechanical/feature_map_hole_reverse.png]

### [[STL]](Preview/Mechanical/feature_sticker.stl) 5. Preview/Mechanical/feature_sticker
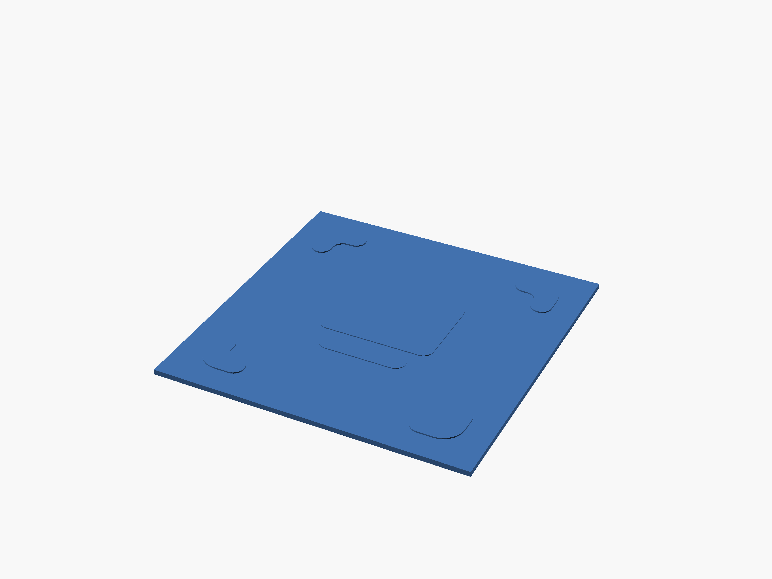
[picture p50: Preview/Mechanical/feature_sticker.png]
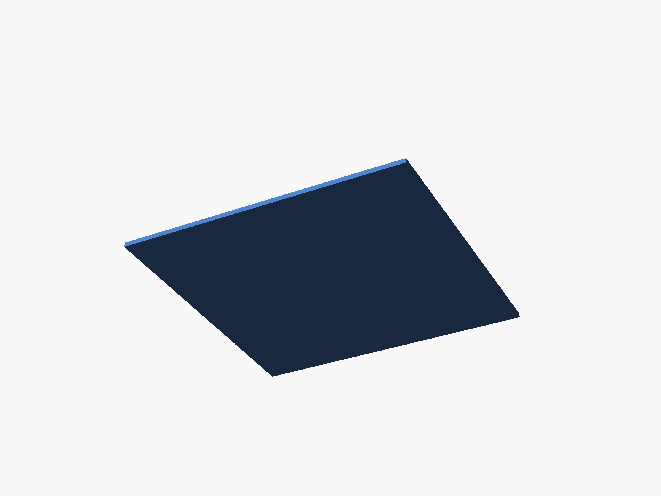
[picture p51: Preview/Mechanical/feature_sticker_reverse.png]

### [[STL]](Preview/Mechanical/feature_magnet_cutout_injection.stl) 6. Preview/Mechanical/feature_magnet_cutout_injection
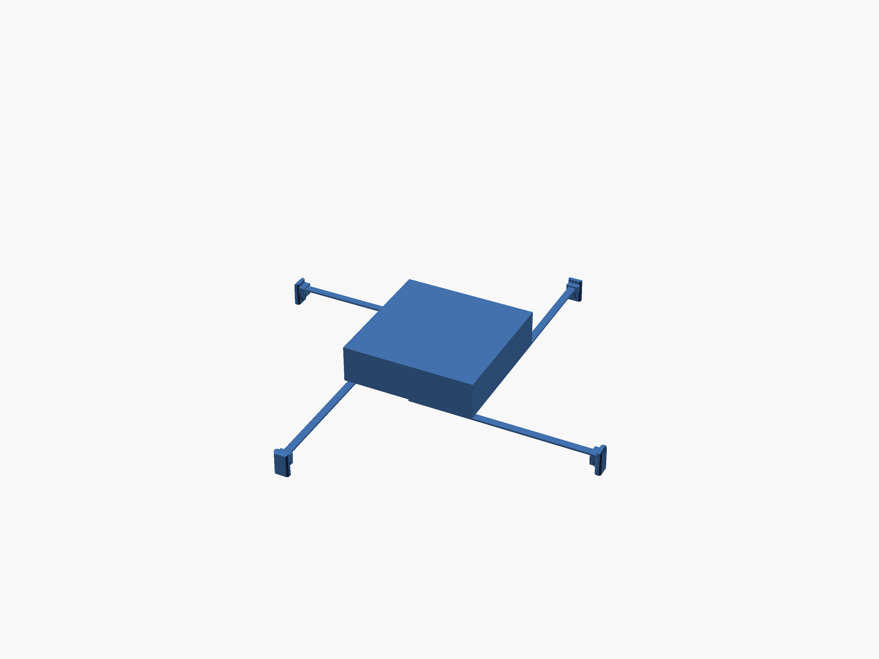
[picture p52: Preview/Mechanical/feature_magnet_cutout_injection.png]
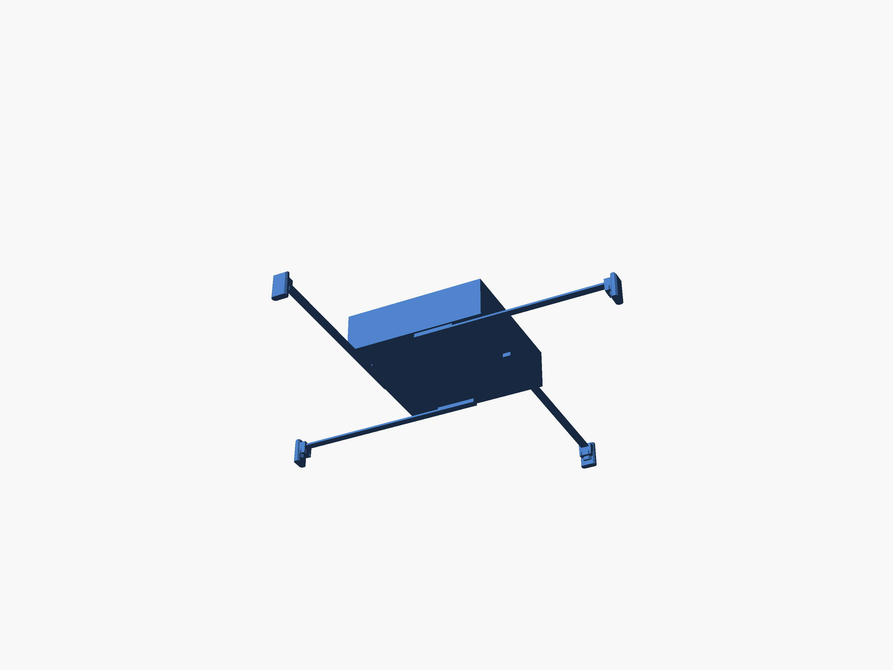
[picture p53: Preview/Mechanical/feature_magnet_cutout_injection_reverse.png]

### [[STL]](Preview/Mechanical/feature_pogo_hole_injection.stl) . Preview/Mechanical/feature_pogo_hole_injection
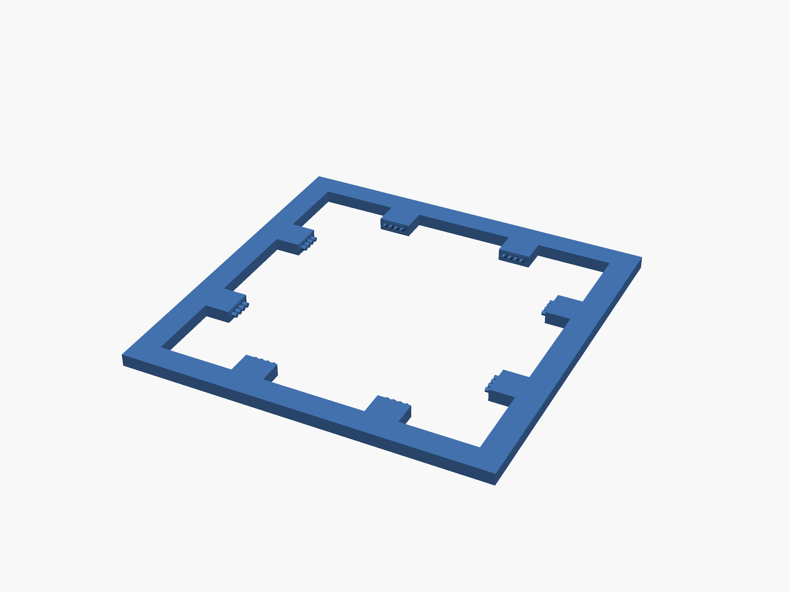
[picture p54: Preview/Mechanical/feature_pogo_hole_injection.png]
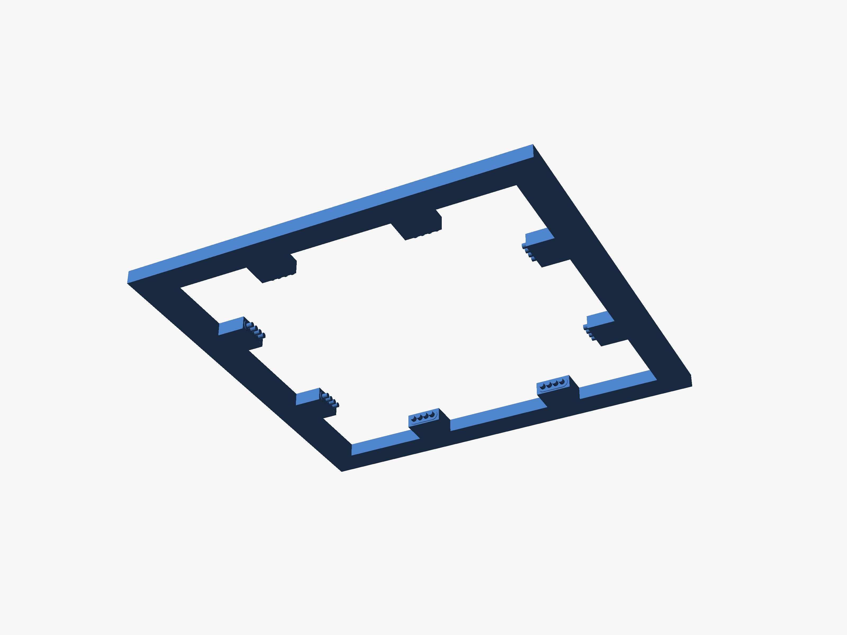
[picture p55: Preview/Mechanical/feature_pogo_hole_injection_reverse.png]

### [[STL]](Preview/Mechanical/feature_subtract_cavity.stl) 8. Preview/Mechanical/feature_subtract_cavity
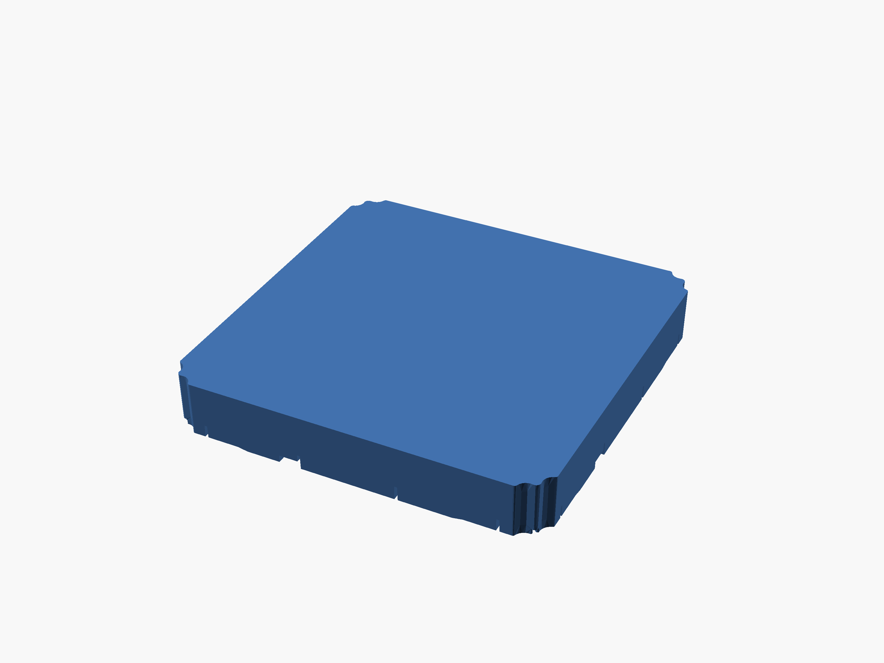
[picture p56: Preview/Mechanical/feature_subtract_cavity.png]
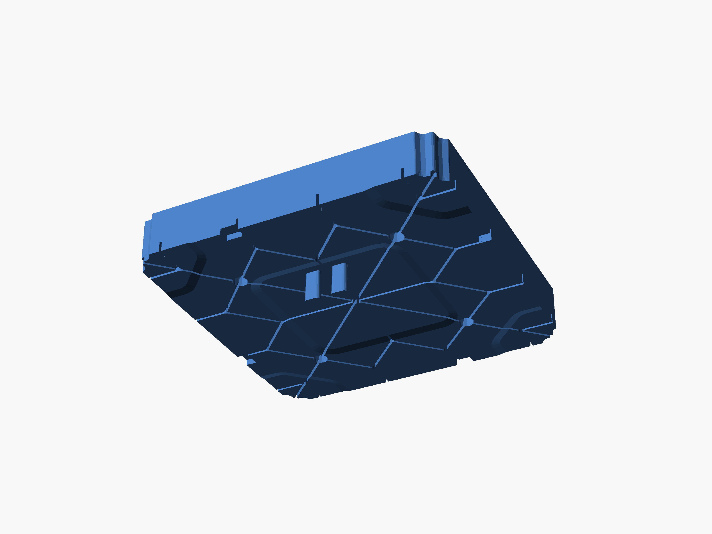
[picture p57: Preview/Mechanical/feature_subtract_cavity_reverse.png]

### [[STL]](Preview/Mechanical/feature_alignment_lip_B.stl) 9. Preview/Mechanical/feature_alignment_lip_B
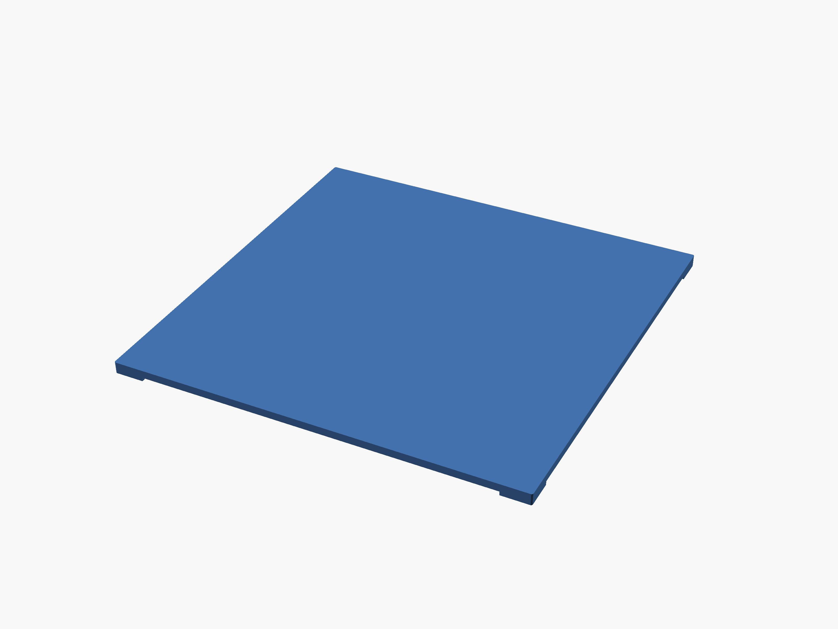
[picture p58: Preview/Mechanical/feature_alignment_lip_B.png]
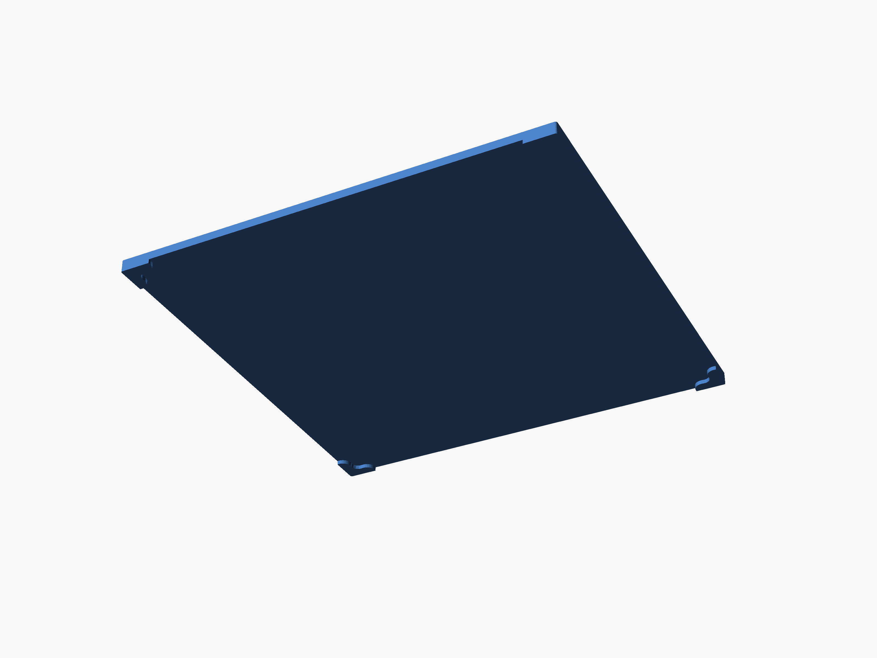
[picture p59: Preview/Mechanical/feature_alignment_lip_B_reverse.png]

### [[STL]](Preview/Mechanical/feature_magent_hole_injection.stl) 10. Preview/Mechanical/feature_magent_hole_injection
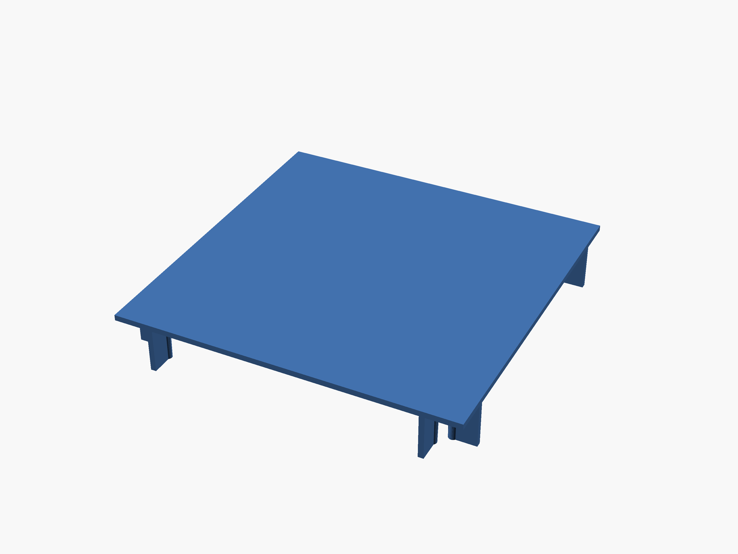
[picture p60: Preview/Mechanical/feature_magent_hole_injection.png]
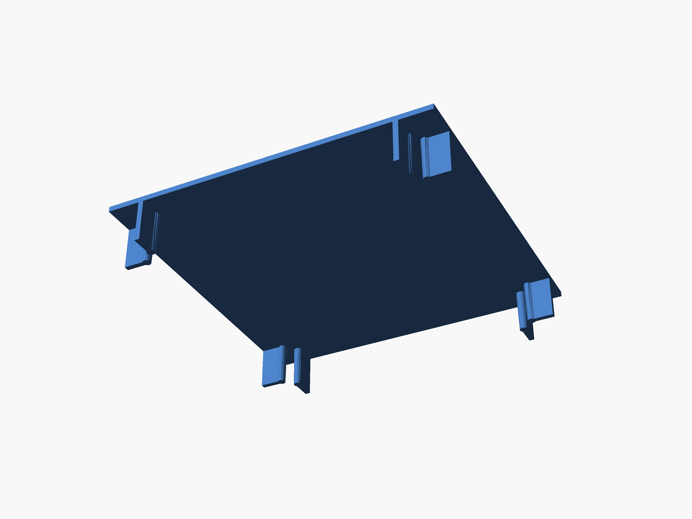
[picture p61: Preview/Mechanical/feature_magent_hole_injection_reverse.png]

### [[STL]](Preview/Mechanical/feature_drill_pattern_inject.stl) 11. Preview/Mechanical/feature_drill_pattern_inject
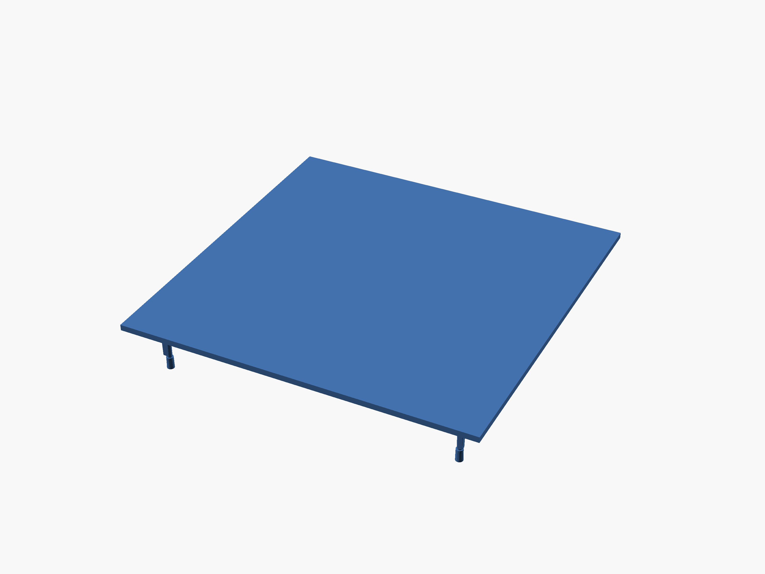
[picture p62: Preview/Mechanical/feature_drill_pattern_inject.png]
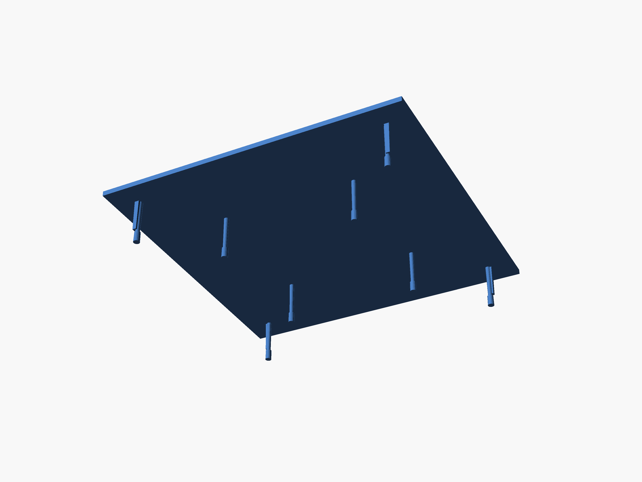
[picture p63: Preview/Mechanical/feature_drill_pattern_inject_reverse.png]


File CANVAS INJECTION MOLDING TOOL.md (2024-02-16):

## THE INJECTION MOLDING TOOL OF CANVAS
Here you can find some highlighted parts of the tooling to demonstrate the molding method.
## THE TOOL
Here you can see the closed tool.
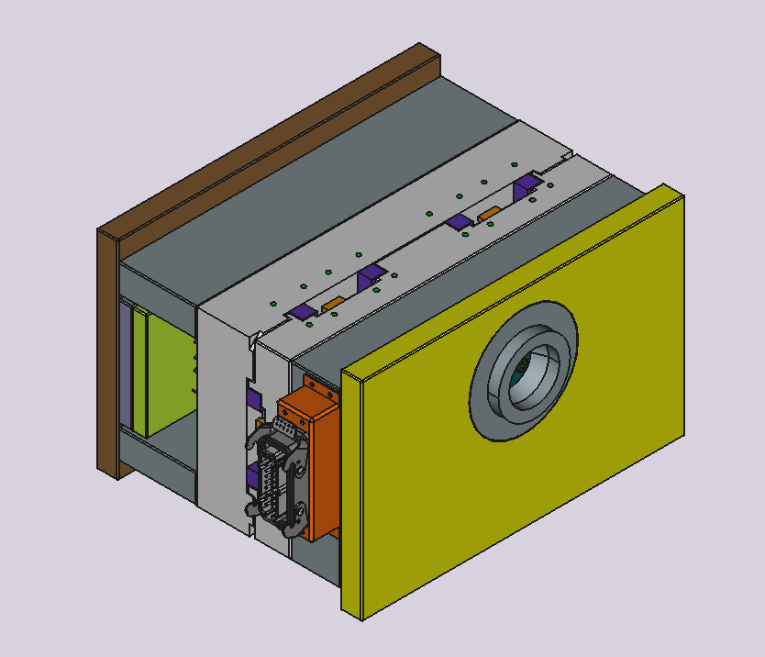
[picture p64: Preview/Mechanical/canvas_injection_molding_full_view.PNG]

The tool can be used to produce 2 parts at the same time.




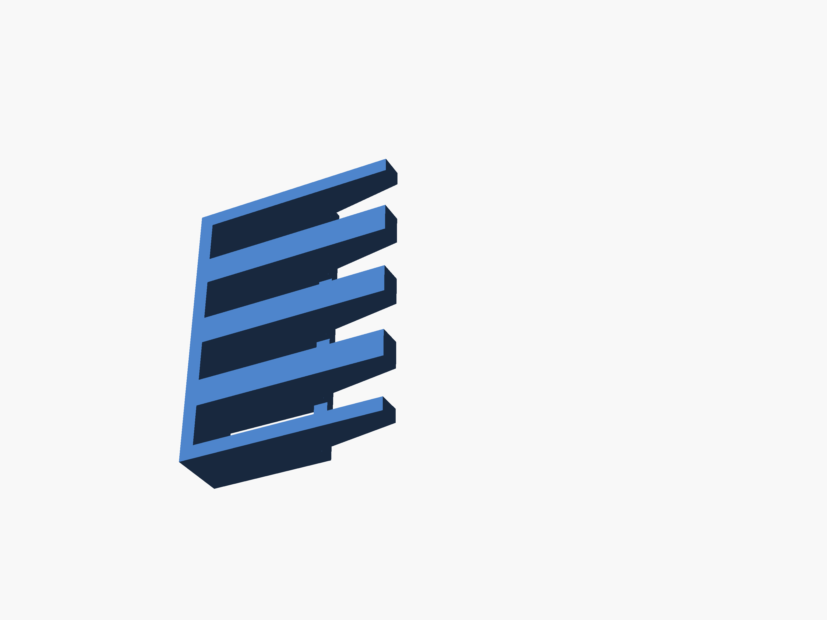
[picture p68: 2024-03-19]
Preview/Mechanical/Body_reverse.png

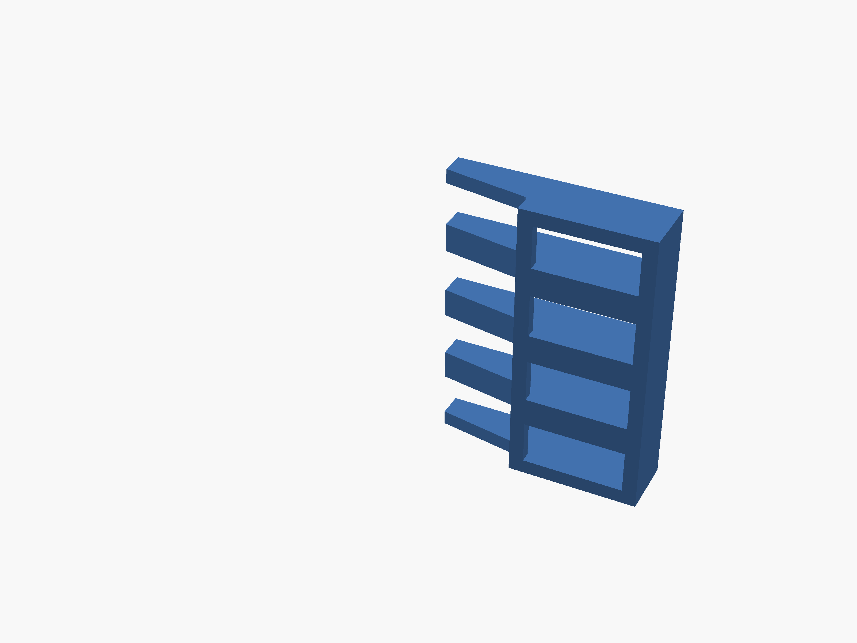
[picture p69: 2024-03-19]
Preview/Mechanical/Body.png

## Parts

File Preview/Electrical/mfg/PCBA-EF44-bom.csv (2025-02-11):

Qty | Designator | Part | Comment | Footprint
1 | C742 | CAP | 1p8 | CAP_0402
1 | C739 | CAP | 3p9 | CAP_0402
2 | C748,C750 | CAP | 10p | CAP_0402
1 | C603 | CAP | 4n7 | CAP_0402
1 | C753 | CAP | 10n | CAP_0402
45 | C731,C732,C735,C736,C737,C738,C740,C741,C744,C745,C747,C749,C751,C752,C756,C757,C801,C901,C902,C905,C906,C909,C910,C913,C914,C1001,C1002,C1003,C1004,C1005,C1006,C1013,C1014,C1015,C1019,C1023,C1027,C1028,C1029,C1030,C1031,C1032,C1048,C1049,C1050 | CAP | 100n | CAP_0402
8 | C601,C602,C733,C734,C746,C754,C755,C758 | CAP | 1u | CAP_0402
1 | C743 | CAP | 10u | CAP_0402
8 | D901,D902,D905,D906,D909,D910,D913,D914 | UI_WS2812C-2020 | WS2812C-2020 | UI_WS2812C-2020
1 | J701 | Conn_Coaxial | C5137195 | U.FL_Molex_MCRF_73412-0110_Vertical
1 | J601 | USB_C_TYPE-C-32-M-12 | TYPE-C-32-M-12 | USB_C_Korean_Hroparts_TYPE-C-31-M-12
1 | L701 | INDUCTOR | 1n8 | IND_0402
2 | L601,L702 | FERRIT | GZ2012D601TF | FERRIT_0805
4 | R1005,R1006,R1007,R1008 | RES | 470R | RES_0402
6 | R733,R736,R1001,R1002,R1003,R1004 | RES | 1k | RES_0402
7 | R601,R602,R701,R729,R734,R735,R801 | RES | 5k1 | RES_0402
24 | R1025,R1026,R1027,R1028,R1029,R1030,R1037,R1038,R1039,R1040,R1041,R1042,R1043,R1044,R1045,R1046,R1047,R1048,R1079,R1080,R1081,R1082,R1083,R1084 | RES | 10k | RES_0402
1 | R603 | RES | 1M | RES_0402
1 | SW701 | SW_SPST | C255807 | SW_HYP_MAPMODE
2 | SW702,SW703 | SW_SPST | C2905169 | SW_SPST_CK_RS282G05A3
3 | U801,U1001,U1005 | 74HC165 | 74HC165 | SOIC-16_74HC165
2 | U1002,U1003 | 74HC4051 | 74HC4051 | SOIC-16_74HC4051
1 | U601 | U_ESD_4ch | C5451661 | SOT-23-6
1 | U704 | ESP32-S3 | ESP32-S3 | QFN-56-1EP_7x7mm_P0.4mm_EP3.2x3.2mm
1 | U602 | U_REGULATOR_SOT23-5 | LN1134A332MR-G | SOT-23-5
1 | U703 | RP2040 | RP2040 | RP2040_QFN-56-1EP_7x7mm_P0.4mm_EP3.2x3.2mm
1 | U705 | U_FLASH_W25Q16JVSSIQ | W25Q64JVSSIQ | SOIC-8W_FLASH
4 | UI1005,UI1007,UI1008,UI1014 | UI_Rotary_Encoder_Switch | ED1115S-20P-20C-13.5F/LAL/N=5/F=7 | UI_ENCODER_SONGHUEI
1 | Y701 | ESP32_XTAL | 40MHz | Crystal_SMD_Abracon_ABM8G-4Pin_3.2x2.5mm

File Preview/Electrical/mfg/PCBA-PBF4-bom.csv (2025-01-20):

Qty | Designator | Part | Comment | Footprint
1 | C742 | CAP | 1p8 | CAP_0402
1 | C739 | CAP | 3p9 | CAP_0402
2 | C748,C750 | CAP | 10p | CAP_0402
1 | C603 | CAP | 4n7 | CAP_0402
1 | C753 | CAP | 10n | CAP_0402
55 | C505,C506,C507,C508,C509,C510,C511,C512,C731,C732,C735,C736,C737,C738,C740,C741,C744,C745,C747,C749,C751,C752,C756,C757,C801,C901,C902,C903,C904,C905,C906,C907,C908,C909,C910,C911,C912,C1001,C1002,C1003,C1004,C1005,C1006,C1007,C1008,C1009,C1010,C1011,C1012,C1013,C1014,C1015,C1016,C1017,C1018 | CAP | 100n | CAP_0402
8 | C601,C602,C733,C734,C746,C754,C755,C758 | CAP | 1u | CAP_0402
1 | C743 | CAP | 10u | CAP_0402
12 | D901,D902,D903,D904,D905,D906,D907,D908,D909,D910,D911,D912 | UI_WS2812C-2020 | WS2812C-2020 | UI_WS2812C-2020
1 | J701 | Conn_Coaxial | C5137195 | U.FL_Molex_MCRF_73412-0110_Vertical
2 | J509,J510 | SMD_NUT | SMTSO1625MTJ | SMD_NUT_M1.6x2.5
1 | J601 | USB_C_TYPE-C-32-M-12 | TYPE-C-32-M-12 | USB_C_Korean_Hroparts_TYPE-C-31-M-12
1 | L701 | INDUCTOR | 1n8 | IND_0402
2 | L601,L702 | FERRIT | GZ2012D601TF | FERRIT_0805
8 | R1017,R1018,R1019,R1020,R1021,R1022,R1023,R1024 | RES | 470R | RES_0402
18 | R733,R736,R1001,R1002,R1003,R1004,R1005,R1006,R1007,R1008,R1009,R1010,R1011,R1012,R1013,R1014,R1015,R1016 | RES | 1k | RES_0402
10 | R519,R523,R527,R531,R601,R602,R701,R729,R734,R735 | RES | 5k1 | RES_0402
4 | R518,R522,R526,R530 | RES | 10k | RES_0402
8 | R517,R520,R521,R524,R525,R528,R529,R532 | RES | 15k | RES_0402
1 | R603 | RES | 1M | RES_0402
1 | SW701 | SW_SPST | C255807 | SW_HYP_MAPMODE
2 | SW702,SW703 | SW_SPST | C2905169 | SW_SPST_CK_RS282G05A3
1 | U801 | 74HC165 | 74HC165 | SOIC-16_74HC165
2 | U1001,U1002 | 74HC4051 | 74HC4051 | SOIC-16_74HC4051
1 | U601 | U_ESD_4ch | C5451661 | SOT-23-6
1 | U704 | ESP32-S3 | ESP32-S3 | QFN-56-1EP_7x7mm_P0.4mm_EP3.2x3.2mm
4 | U509,U510,U511,U512 | LM321 | LMV321 | SOT-23-5
1 | U602 | U_REGULATOR_SOT23-5 | LN1134A332MR-G | SOT-23-5
4 | U505,U506,U507,U508 | A1301KLHLT-T | OH49E-S | SOT-23W
1 | U703 | RP2040 | RP2040 | RP2040_QFN-56-1EP_7x7mm_P0.4mm_EP3.2x3.2mm
1 | U705 | U_FLASH_W25Q16JVSSIQ | W25Q64JVSSIQ | SOIC-8W_FLASH
4 | UI1001,UI1003,UI1005,UI1007 | UI_Potentiometer | RK0952N-12.5F/5-B10K | UI_POT_SONGHUEI
1 | Y701 | ESP32_XTAL | 40MHz | Crystal_SMD_Abracon_ABM8G-4Pin_3.2x2.5mm

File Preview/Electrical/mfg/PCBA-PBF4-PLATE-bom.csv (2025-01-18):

Qty | Designator | Part | Comment | Footprint
1 | LOGO701 | LOGO | LOGO | OSHWA

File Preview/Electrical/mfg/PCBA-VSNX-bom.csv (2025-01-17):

Qty | Designator | Part | Comment | Footprint
1 | C742 | CAP | 1p8 | CAP_0402
1 | C739 | CAP | 3p9 | CAP_0402
2 | C748,C750 | CAP | 10p | CAP_0402
2 | C939,C940 | CAP | 1n | CAP_0402
1 | C603 | CAP | 4n7 | CAP_0402
1 | C753 | CAP | 10n | CAP_0402
71 | C731,C732,C735,C736,C737,C738,C740,C741,C744,C745,C747,C749,C751,C752,C756,C757,C801,C901,C902,C903,C904,C905,C906,C907,C908,C909,C910,C911,C912,C913,C914,C915,C916,C917,C918,C919,C920,C921,C922,C923,C924,C925,C926,C927,C928,C929,C930,C931,C932,C933,C934,C935,C936,C1001,C1002,C1003,C1004,C1005,C1006,C1007,C1008,C1009,C1010,C1011,C1012,C1013,C1014,C1015,C1016,C1017,C1018 | CAP | 100n | CAP_0402
9 | C601,C602,C733,C734,C746,C754,C755,C758,C937 | CAP | 1u | CAP_0402
2 | C743,C938 | CAP | 10u | CAP_0402
18 | D901,D902,D903,D904,D905,D906,D907,D908,D909,D910,D911,D912,D913,D914,D915,D916,D917,D918 | UI_WS2812C-2020 | WS2812C-2020 | UI_WS2812C-2020
1 | J701 | Conn_Coaxial | C5137195 | U.FL_Molex_MCRF_73412-0110_Vertical
8 | J903,J904,J905,J906,J909,J910,J911,J912 | SMD_NUT | SMTSO1625MTJ | SMD_NUT_M1.6x2.5
1 | J601 | USB_C_TYPE-C-32-M-12 | TYPE-C-32-M-12 | USB_C_Korean_Hroparts_TYPE-C-31-M-12
1 | L701 | INDUCTOR | 1n8 | IND_0402
2 | L902,L903 | FERRIT | BLM15AG102SN1D | FERRIT_0402
1 | L904 | FERRIT | BLM15PD121SN1D | FERRIT_0402
2 | L601,L702 | FERRIT | GZ2012D601TF | FERRIT_0805
1 | R939 | RES | 0R | RES_0402
3 | R940,R941,R942 | RES | 33R | RES_0402
2 | R902,R1025 | RES | 470R | RES_0402
18 | R733,R736,R1001,R1002,R1003,R1004,R1005,R1006,R1007,R1008,R1009,R1010,R1011,R1012,R1013,R1014,R1015,R1016 | RES | 1k | RES_0402
25 | R601,R602,R701,R729,R734,R735,R801,R802,R901,R904,R906,R907,R908,R909,R913,R917,R921,R925,R929,R933,R937,R1021,R1022,R1023,R1024 | RES | 5k1 | RES_0402
8 | R905,R912,R916,R920,R924,R928,R932,R936 | RES | 10k | RES_0402
16 | R903,R910,R911,R914,R915,R918,R919,R922,R923,R926,R927,R930,R931,R934,R935,R938 | RES | 15k | RES_0402
1 | R603 | RES | 1M | RES_0402
1 | SW701 | SW_SPST | C255807 | SW_HYP_MAPMODE
10 | SW702,SW703,SW905,SW906,SW907,SW908,SW1001,SW1002,SW1003,SW1004 | SW_SPST | C2905169 | SW_SPST_CK_RS282G05A3
1 | U801 | 74HC165 | 74HC165 | SOIC-16_74HC165
2 | U1001,U1002 | 74HC4051 | 74HC4051 | SOIC-16_74HC4051
1 | U601 | U_ESD_4ch | C5451661 | SOT-23-6-AND-SOT-363
1 | U903 | ESP-PSRAM | ESP-PSRAM32 | SOIC-8_3.9x4.9mm_P1.27mm
1 | U704 | ESP32-S3 | ESP32-S3 | QFN-56-1EP_7x7mm_P0.4mm_EP3.2x3.2mm
8 | U910,U911,U912,U913,U914,U915,U916,U917 | LM321 | LMV321 | SOT-23-5
1 | U602 | U_REGULATOR_SOT23-5 | LN1134A332MR-G | SOT-23-5
1 | U918 | NS4168_C910588 | NS4168_C910588 | ESOP-8_L4.9-W3.9-P1.27-LS6.0-BL-EP
8 | U901,U902,U904,U905,U906,U907,U908,U909 | A1301KLHLT-T | OH49E-S | SOT-23W
1 | U703 | RP2040 | RP2040 | RP2040_QFN-56-1EP_7x7mm_P0.4mm_EP3.2x3.2mm
1 | U705 | U_FLASH_W25Q16JVSSIQ | W25Q64JVSSIQ | SOIC-8W_FLASH
1 | Y701 | ESP32_XTAL | 40MHz | Crystal_SMD_Abracon_ABM8G-4Pin_3.2x2.5mm

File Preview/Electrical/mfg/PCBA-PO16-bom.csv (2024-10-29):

Qty | Designator | Part | Comment | Footprint
1 | C742 | CAP | 1p8 | CAP_0402
1 | C739 | CAP | 3p9 | CAP_0402
2 | C748,C750 | CAP | 10p | CAP_0402
1 | C603 | CAP | 4n7 | CAP_0402
1 | C753 | CAP | 10n | CAP_0402
51 | C731,C732,C735,C736,C737,C738,C740,C741,C744,C745,C747,C749,C751,C752,C756,C757,C801,C901,C902,C903,C904,C905,C906,C907,C908,C909,C910,C911,C912,C913,C914,C915,C916,C1001,C1002,C1003,C1004,C1005,C1006,C1007,C1008,C1009,C1010,C1011,C1012,C1013,C1014,C1015,C1016,C1017,C1018 | CAP | 100n | CAP_0402
8 | C601,C602,C733,C734,C746,C754,C755,C758 | CAP | 1u | CAP_0402
1 | C743 | CAP | 10u | CAP_0402
16 | D901,D902,D903,D904,D905,D906,D907,D908,D909,D910,D911,D912,D913,D914,D915,D916 | UI_WS2812C-2020 | WS2812C-2020 | UI_WS2812C-2020
1 | J701 | Conn_Coaxial | C5137195 | U.FL_Molex_MCRF_73412-0110_Vertical
1 | J601 | USB_C_TYPE-C-32-M-12 | TYPE-C-32-M-12 | USB_C_Korean_Hroparts_TYPE-C-31-M-12
1 | L701 | INDUCTOR | 1n8 | IND_0402
2 | L601,L702 | FERRIT | GZ2012D601TF | FERRIT_0805
16 | R1017,R1018,R1019,R1020,R1021,R1022,R1023,R1024,R1025,R1026,R1027,R1028,R1029,R1030,R1031,R1032 | RES | 470R | RES_0402
18 | R733,R736,R1001,R1002,R1003,R1004,R1005,R1006,R1007,R1008,R1009,R1010,R1011,R1012,R1013,R1014,R1015,R1016 | RES | 1k | RES_0402
24 | R601,R602,R701,R702,R729,R734,R735,R801,R1033,R1034,R1035,R1036,R1037,R1038,R1039,R1040,R1041,R1042,R1043,R1044,R1045,R1046,R1047,R1048 | RES | 5k1 | RES_0402
1 | R603 | RES | 1M | RES_0402
1 | SW701 | SW_SPST | C255807 | SW_HYP_MAPMODE
2 | SW702,SW703 | SW_SPST | C2905169 | SW_SPST_CK_RS282G05A3
1 | U801 | 74HC165 | 74HC165 | SOIC-16_74HC165
2 | U1001,U1002 | 74HC4051 | 74HC4051 | SOIC-16_74HC4051
1 | U601 | U_ESD_4ch | C5451661 | SOT-23-6
1 | U704 | ESP32-S3 | ESP32-S3 | QFN-56-1EP_7x7mm_P0.4mm_EP3.2x3.2mm
1 | U602 | U_REGULATOR_SOT23-5 | LN1134A332MR-G | SOT-23-5
1 | U703 | RP2040 | RP2040 | RP2040_QFN-56-1EP_7x7mm_P0.4mm_EP3.2x3.2mm
1 | U705 | U_FLASH_W25Q16JVSSIQ | W25Q64JVSSIQ | SOIC-8W_FLASH
16 | UI1001,UI1002,UI1003,UI1004,UI1005,UI1006,UI1007,UI1008,UI1009,UI1010,UI1011,UI1012,UI1013,UI1014,UI1015,UI1016 | UI_Potentiometer | RK0952N-12.5F/5-B10K | UI_POT_SONGHUEI
1 | Y701 | ESP32_XTAL | 40MHz | Crystal_SMD_Abracon_ABM8G-4Pin_3.2x2.5mm

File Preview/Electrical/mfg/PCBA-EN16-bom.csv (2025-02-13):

Qty | Designator | Part | Comment | Footprint
1 | C742 | CAP | 1p8 | CAP_0402
1 | C739 | CAP | 3p9 | CAP_0402
2 | C748,C750 | CAP | 10p | CAP_0402
1 | C603 | CAP | 4n7 | CAP_0402
1 | C753 | CAP | 10n | CAP_0402
93 | C501,C502,C503,C504,C731,C732,C735,C736,C737,C738,C740,C741,C744,C745,C747,C749,C751,C752,C756,C757,C801,C901,C902,C903,C904,C905,C906,C907,C908,C909,C910,C911,C912,C913,C914,C915,C916,C1001,C1002,C1003,C1004,C1005,C1006,C1007,C1008,C1009,C1010,C1011,C1012,C1013,C1014,C1015,C1016,C1017,C1018,C1019,C1020,C1021,C1022,C1023,C1024,C1025,C1026,C1027,C1028,C1029,C1030,C1031,C1032,C1033,C1034,C1035,C1036,C1037,C1038,C1039,C1040,C1041,C1042,C1043,C1044,C1045,C1046,C1047,C1048,C1049,C1050,C1051,C1052,C1053,C1054,C1055,C1056 | CAP | 100n | CAP_0402
8 | C601,C602,C733,C734,C746,C754,C755,C758 | CAP | 1u | CAP_0402
1 | C743 | CAP | 10u | CAP_0402
16 | D901,D902,D903,D904,D905,D906,D907,D908,D909,D910,D911,D912,D913,D914,D915,D916 | UI_WS2812C-2020 | WS2812C-2020 | UI_WS2812C-2020
1 | J701 | Conn_Coaxial | C5137195 | U.FL_Molex_MCRF_73412-0110_Vertical
1 | J601 | USB_C_TYPE-C-32-M-12 | TYPE-C-32-M-12 | USB_C_Korean_Hroparts_TYPE-C-31-M-12
1 | L701 | INDUCTOR | 1n8 | IND_0402
1 | L702 | FERRIT | GZ2012D601TF | FERRIT_0805
2 | R501,R736 | RES | 1k | RES_0402
7 | R601,R602,R701,R729,R734,R735,R801 | RES | 5k1 | RES_0402
96 | R1001,R1002,R1003,R1004,R1005,R1006,R1007,R1008,R1009,R1010,R1011,R1012,R1013,R1014,R1015,R1016,R1017,R1018,R1019,R1020,R1021,R1022,R1023,R1024,R1025,R1026,R1027,R1028,R1029,R1030,R1031,R1032,R1033,R1034,R1035,R1036,R1037,R1038,R1039,R1040,R1041,R1042,R1043,R1044,R1045,R1046,R1047,R1048,R1049,R1050,R1051,R1052,R1053,R1054,R1055,R1056,R1057,R1058,R1059,R1060,R1061,R1062,R1063,R1064,R1065,R1066,R1067,R1068,R1069,R1070,R1071,R1072,R1073,R1074,R1075,R1076,R1077,R1078,R1079,R1080,R1081,R1082,R1083,R1084,R1085,R1086,R1087,R1088,R1089,R1090,R1091,R1092,R1093,R1094,R1095,R1096 | RES | 10k | RES_0402
1 | R603 | RES | 1M | RES_0402
1 | SW701 | SW_SPST | C255807 | SW_HYP_MAPMODE
2 | SW702,SW703 | SW_SPST | C2905169 | SW_SPST_CK_RS282G05A3
9 | U801,U1001,U1002,U1003,U1004,U1005,U1006,U1007,U1008 | 74HC165 | 74HC165 | SOIC-16_74HC165
1 | U502 | 74LVC1G08 | 74LVC1G08 | SOT-23-5-AND-TSSOP5
4 | U501,U503,U505,U506 | BL1551B | BL1551B | SOT-363_SC-70-6
2 | U504,U507 | U_ESD_4ch | C5451661 | SOT-23-6
1 | U704 | ESP32-S3 | ESP32-S3 | QFN-56-1EP_7x7mm_P0.4mm_EP3.2x3.2mm
1 | U602 | U_REGULATOR_SOT23-5 | LN1134A332MR-G | SOT-23-5
1 | U703 | RP2040 | RP2040 | RP2040_QFN-56-1EP_7x7mm_P0.4mm_EP3.2x3.2mm
1 | U705 | U_FLASH_W25Q16JVSSIQ | W25Q64JVSSIQ | SOIC-8W_FLASH
16 | UI1001,UI1002,UI1003,UI1004,UI1005,UI1006,UI1007,UI1008,UI1009,UI1010,UI1011,UI1012,UI1013,UI1014,UI1015,UI1016 | UI_Rotary_Encoder_Switch | ED1115S-20P-20C-13.5F/LAL/N=5/F=7 | UI_ENCODER_SONGHUEI
1 | Y701 | ESP32_XTAL | 40MHz | Crystal_SMD_Abracon_ABM8G-4Pin_3.2x2.5mm

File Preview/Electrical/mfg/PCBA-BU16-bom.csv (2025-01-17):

Qty | Designator | Part | Comment | Footprint
1 | C742 | CAP | 1p8 | CAP_0402
1 | C739 | CAP | 3p9 | CAP_0402
2 | C748,C750 | CAP | 10p | CAP_0402
1 | C603 | CAP | 4n7 | CAP_0402
1 | C753 | CAP | 10n | CAP_0402
83 | C731,C732,C735,C736,C737,C738,C740,C741,C744,C745,C747,C749,C751,C752,C756,C757,C801,C901,C902,C903,C904,C905,C906,C907,C908,C909,C910,C911,C912,C913,C914,C915,C916,C1001,C1002,C1003,C1004,C1005,C1006,C1007,C1008,C1009,C1010,C1011,C1012,C1013,C1014,C1015,C1016,C1017,C1018,C1019,C1020,C1021,C1022,C1023,C1024,C1025,C1026,C1027,C1028,C1029,C1030,C1031,C1032,C1033,C1034,C1035,C1036,C1037,C1038,C1039,C1040,C1041,C1042,C1043,C1044,C1045,C1046,C1047,C1048,C1049,C1050 | CAP | 100n | CAP_0402
8 | C601,C602,C733,C734,C746,C754,C755,C758 | CAP | 1u | CAP_0402
1 | C743 | CAP | 10u | CAP_0402
16 | D901,D902,D903,D904,D905,D906,D907,D908,D909,D910,D911,D912,D913,D914,D915,D916 | UI_WS2812C-2020 | WS2812C-2020 | UI_WS2812C-2020
1 | J701 | Conn_Coaxial | C5137195 | U.FL_Molex_MCRF_73412-0110_Vertical
4 | J1005,J1006,J1007,J1008 | SMD_NUT | SMTSO1625MTJ | SMD_NUT_M1.6x2.5
4 | J1001,J1002,J1003,J1004 | SMTSO1625MTJ | SMTSO1625MTJ | SMD_NUT_M1.6x2.5
1 | J601 | USB_C_TYPE-C-32-M-12 | TYPE-C-32-M-12 | USB_C_Korean_Hroparts_TYPE-C-31-M-12
1 | L701 | INDUCTOR | 1n8 | IND_0402
2 | L601,L702 | FERRIT | GZ2012D601TF | FERRIT_0805
18 | R733,R736,R1001,R1002,R1003,R1004,R1005,R1006,R1007,R1008,R1009,R1010,R1011,R1012,R1013,R1014,R1015,R1016 | RES | 1k | RES_0402
22 | R601,R602,R701,R729,R734,R735,R1017,R1021,R1025,R1029,R1033,R1037,R1041,R1045,R1049,R1053,R1057,R1061,R1065,R1069,R1073,R1077 | RES | 5k1 | RES_0402
16 | R1018,R1022,R1026,R1030,R1034,R1038,R1042,R1046,R1050,R1054,R1058,R1062,R1066,R1070,R1074,R1078 | RES | 10k | RES_0402
32 | R1019,R1020,R1023,R1024,R1027,R1028,R1031,R1032,R1035,R1036,R1039,R1040,R1043,R1044,R1047,R1048,R1051,R1052,R1055,R1056,R1059,R1060,R1063,R1064,R1067,R1068,R1071,R1072,R1075,R1076,R1079,R1080 | RES | 15k | RES_0402
1 | R603 | RES | 1M | RES_0402
1 | SW701 | SW_SPST | C255807 | SW_HYP_MAPMODE
2 | SW702,SW703 | SW_SPST | C2905169 | SW_SPST_CK_RS282G05A3
1 | U801 | 74HC165 | 74HC165 | SOIC-16_74HC165
2 | U1001,U1002 | 74HC4051 | 74HC4051 | SOIC-16_74HC4051
1 | U601 | U_ESD_4ch | C5451661 | SOT-23-6
1 | U704 | ESP32-S3 | ESP32-S3 | QFN-56-1EP_7x7mm_P0.4mm_EP3.2x3.2mm
16 | U1019,U1020,U1021,U1022,U1023,U1024,U1025,U1026,U1027,U1028,U1029,U1030,U1031,U1032,U1033,U1034 | LM321 | LMV321 | SOT-23-5
1 | U602 | U_REGULATOR_SOT23-5 | LN1134A332MR-G | SOT-23-5
16 | U1003,U1004,U1005,U1006,U1007,U1008,U1009,U1010,U1011,U1012,U1013,U1014,U1015,U1016,U1017,U1018 | A1301KLHLT-T | OH49E-S | SOT-23W
1 | U703 | RP2040 | RP2040 | RP2040_QFN-56-1EP_7x7mm_P0.4mm_EP3.2x3.2mm
1 | U705 | U_FLASH_W25Q16JVSSIQ | W25Q64JVSSIQ | SOIC-8W_FLASH
1 | Y701 | ESP32_XTAL | 40MHz | Crystal_SMD_Abracon_ABM8G-4Pin_3.2x2.5mm

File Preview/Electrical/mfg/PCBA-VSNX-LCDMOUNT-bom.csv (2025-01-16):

Qty | Designator | Part | Comment | Footprint
2 | C1002,C1004 | CAP | 100n | CAP_0402
2 | C1001,C1003 | CAP | 1u | CAP_0402
4 | J1001,J1002,J1007,J1008 | Conn_01x04 | BC-12-4PD170-08 | J_BATTERY_CONN
1 | LOGO701 | LOGO | LOGO | OSHWA
1 | Q1001 | 2N7002 | 2N7002 | SOT-23
2 | R1002,R1003 | RES | 47R | RES_0402
7 | R1001,R1004,R1005,R1006,R1007,R1008,R1009 | RES | 10k | RES_0402
2 | U1001,U1002 | DISPLAY_TEK1 | DISPLAY_TEK1 | Display_VSN1_flat

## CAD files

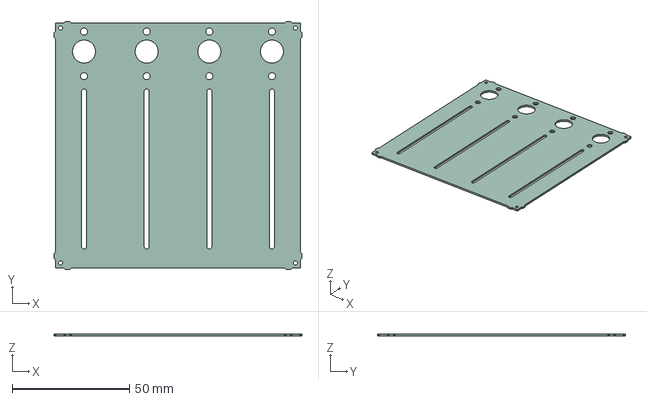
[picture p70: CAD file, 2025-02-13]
Preview/Electrical/FP-EF44-3D.step
105.6 x 105.6 x 1.00 mm

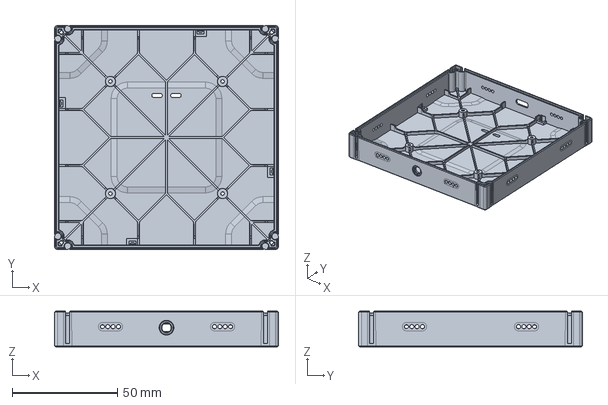
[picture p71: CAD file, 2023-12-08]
Preview/Mechanical/Canvas/PLASTIC-HOUSING.step
106.6 x 106.6 x 17.0 mm

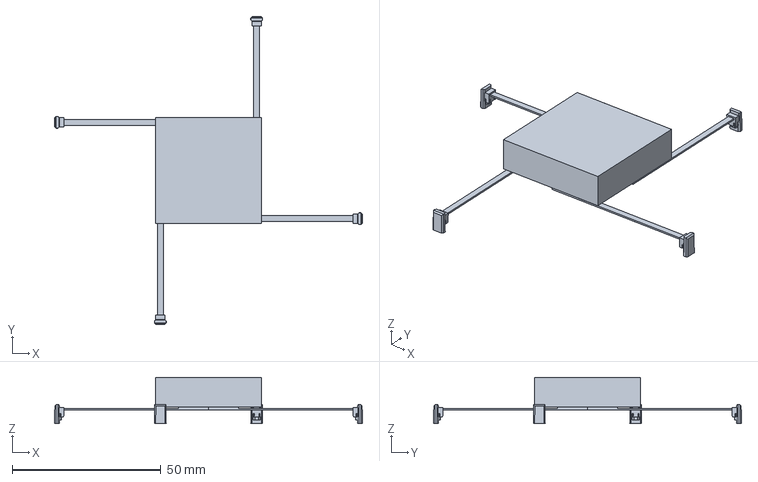
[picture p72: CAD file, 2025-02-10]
Preview/Mechanical/feature_magnet_cutout_injection.step
103.4 x 103.4 x 15.5 mm

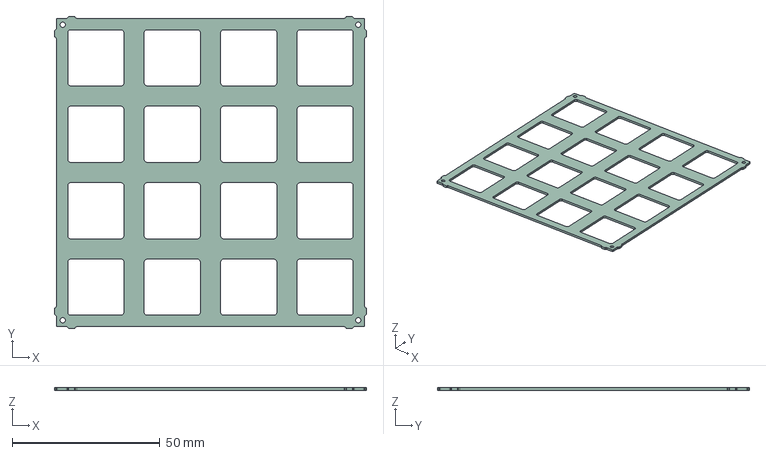
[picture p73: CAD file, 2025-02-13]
Preview/Electrical/FP-BU16-3D.step
105.6 x 105.6 x 1.00 mm

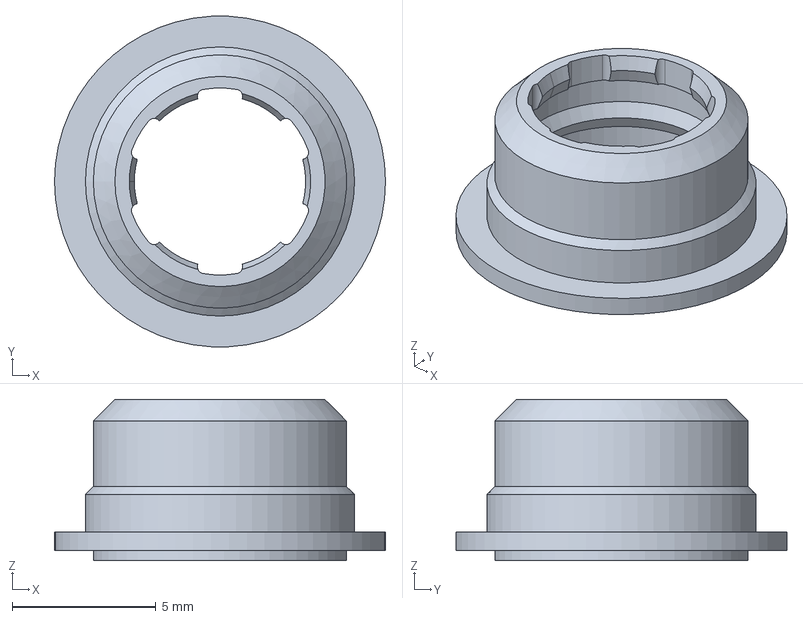
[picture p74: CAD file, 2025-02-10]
Preview/Mechanical/PLASTIC-BUSHING-POT_Printed.step
11.5 x 11.5 x 5.60 mm

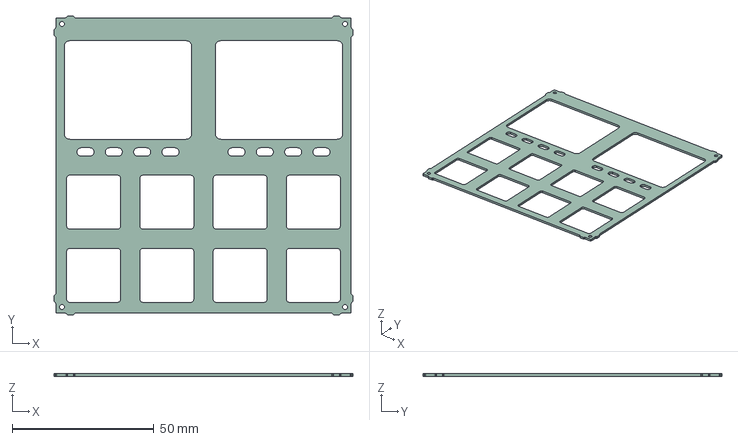
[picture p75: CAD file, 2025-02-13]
Preview/Electrical/FP-VSN2-3D.step
105.6 x 105.6 x 1.00 mm

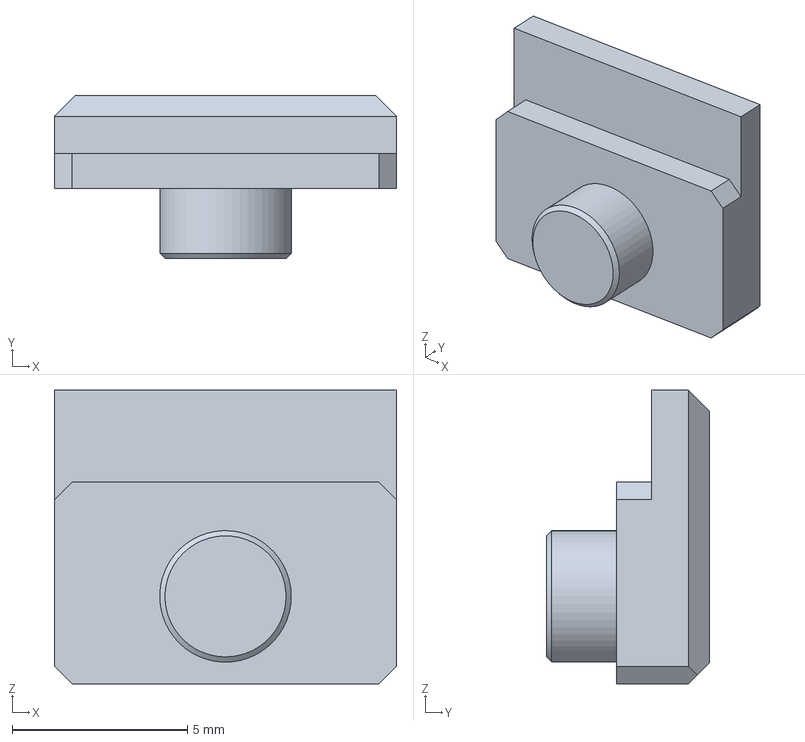
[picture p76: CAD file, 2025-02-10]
Preview/Mechanical/PLASTIC-MAPMODE.step
9.75 x 4.65 x 8.38 mm

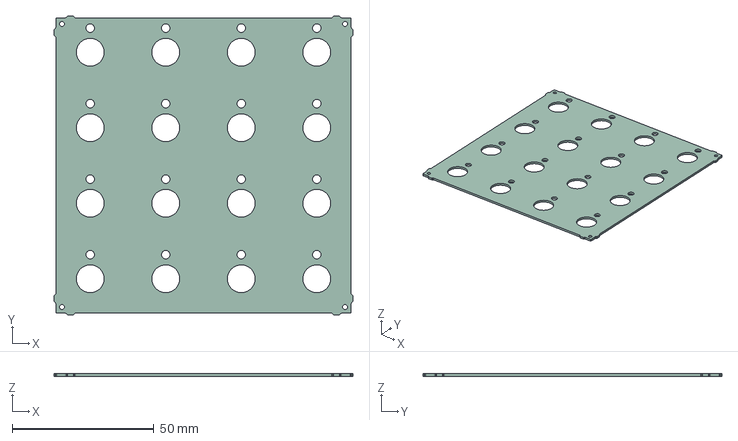
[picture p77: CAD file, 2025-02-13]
Preview/Electrical/FP-BU16-MIDIGRADE-3D.step
105.6 x 105.6 x 1.00 mm

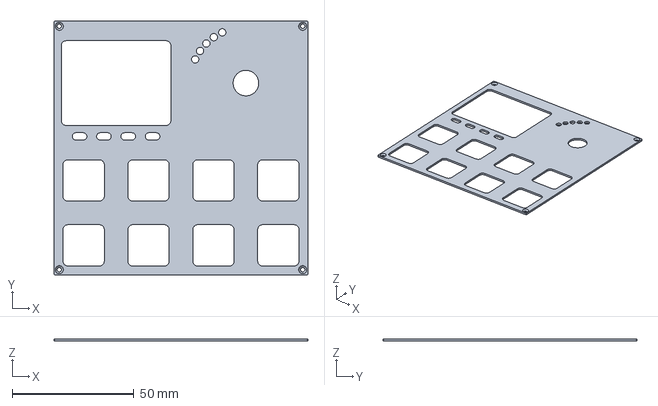
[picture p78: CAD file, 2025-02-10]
Preview/Mechanical/FRONTPANEL-SHEET-VSN1.step
104.3 x 104.3 x 1.00 mm

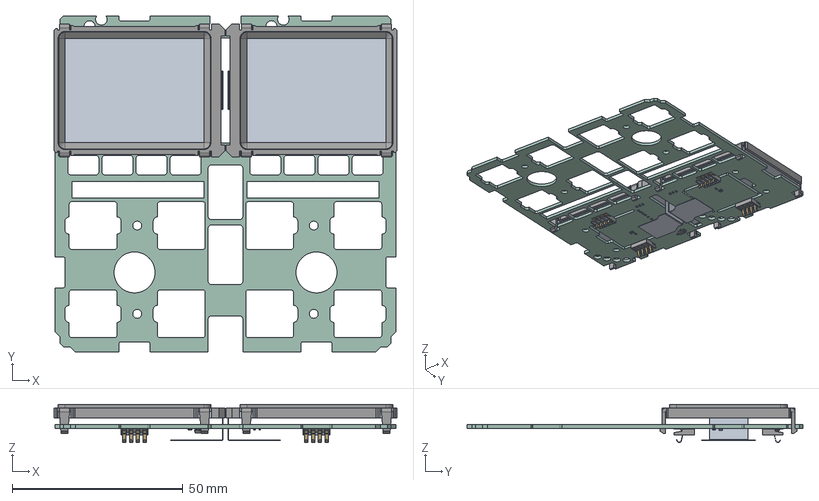
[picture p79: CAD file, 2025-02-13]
Preview/Electrical/PCBA-VSNX-LCDMOUNT-3D.step
100.4 x 98.5 x 11.2 mm
PLASTIC-VSN1-DISPLAY-INTERFACE x 2
R_0402_1005Metric x 9
battery_spring x 4
C_0402_1005Metric x 4
SOT_23
kibot_qcv60soq_PCB

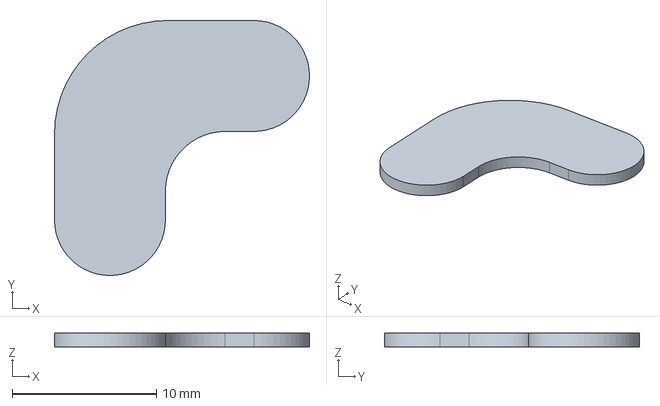
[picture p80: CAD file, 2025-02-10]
Preview/Mechanical/RUBBER-FOOT.step
17.7 x 17.7 x 1.00 mm

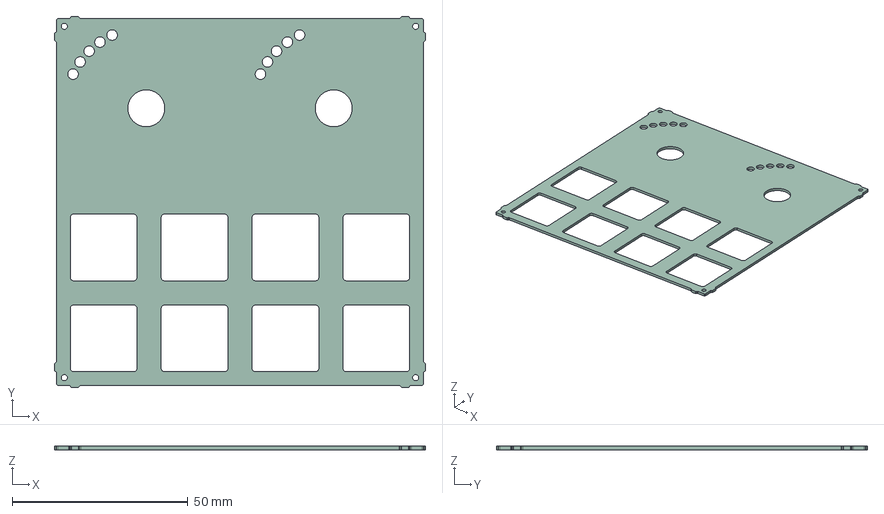
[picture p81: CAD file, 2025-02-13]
Preview/Electrical/FP-TEK2-3D.step
105.6 x 105.6 x 1.00 mm

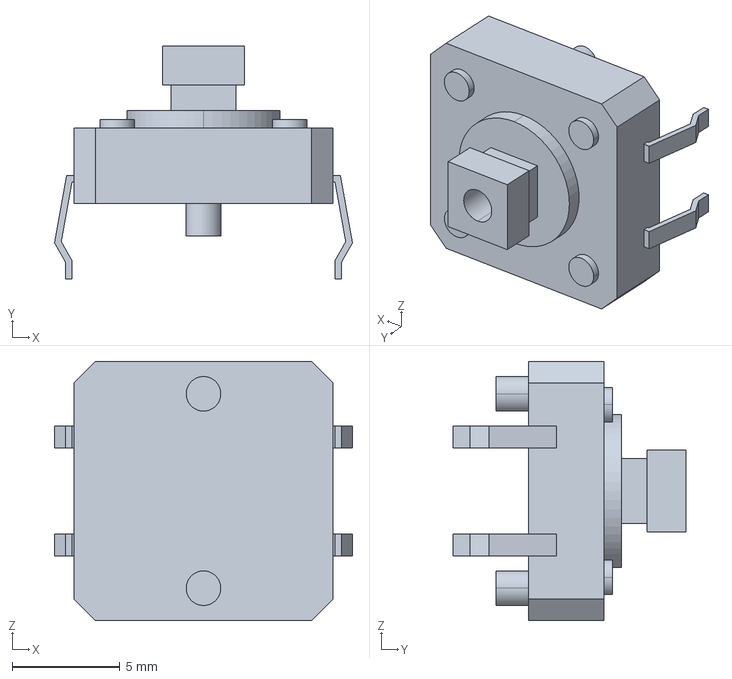
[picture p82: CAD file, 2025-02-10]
Preview/Mechanical/PCBA-BUTTON.step
13.8 x 10.8 x 12.0 mm

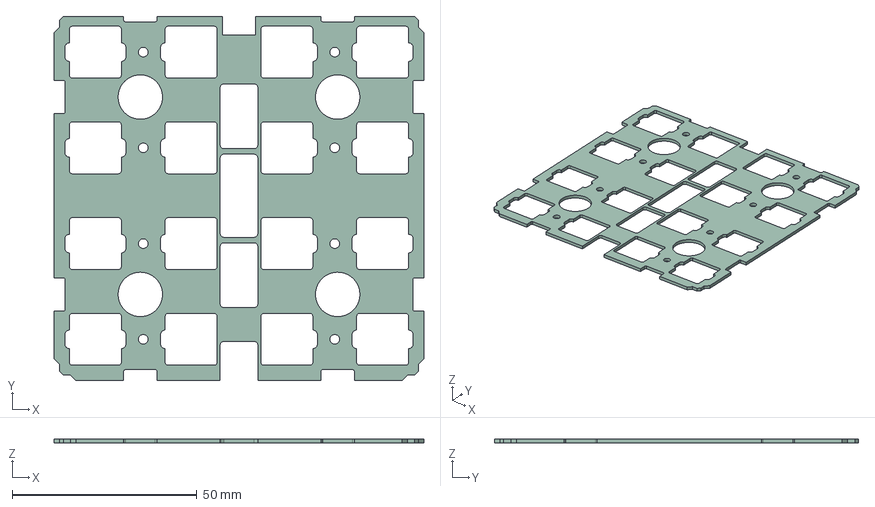
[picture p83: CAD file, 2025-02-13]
Preview/Electrical/PCBA-BU16-PLATE-3D.step
100.0 x 98.5 x 1.20 mm

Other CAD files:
Preview/Mechanical/Body001.step
Preview/Electrical/PCBA-INTERFACE-3D.step
Preview/Mechanical/Spring2.step
Preview/Electrical/PCBA-BU16-3D.step
Preview/Electrical/FP-EN16-MIDIGRADE-3D.step
Preview/Electrical/FP-PBF4-3D.step
Preview/Electrical/FP-VSN0-3D.step
Preview/Electrical/FP-VSN1-3D.step
Preview/Electrical/FP-VSN1-L-3D.step
Preview/Electrical/FP-VSN1-R-3D.step
Preview/Electrical/FP-VSN1R-3D.step
Preview/Electrical/FP-XX16-3D.step
Preview/Electrical/PCBA-BU16-FRONTPANEL-3D.step
Preview/Electrical/PCBA-BU16-SPACER-3D.step
Preview/Electrical/PCBA-EF44-3D.step
Preview/Electrical/PCBA-EF44-FRONTPANEL-3D.step
Preview/Electrical/PCBA-EN16-3D.step
Preview/Electrical/PCBA-PBF4-FRONTPANEL-3D.step
Preview/Electrical/PCBA-PBF4-PLATE-3D.step
Preview/Electrical/PCBA-PBF4-SPACER-3D.step
Preview/Electrical/PCBA-TEK1-BTNGROUP-3D.step
Preview/Electrical/PCBA-VSN0-FRONTPANEL-3D.step
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

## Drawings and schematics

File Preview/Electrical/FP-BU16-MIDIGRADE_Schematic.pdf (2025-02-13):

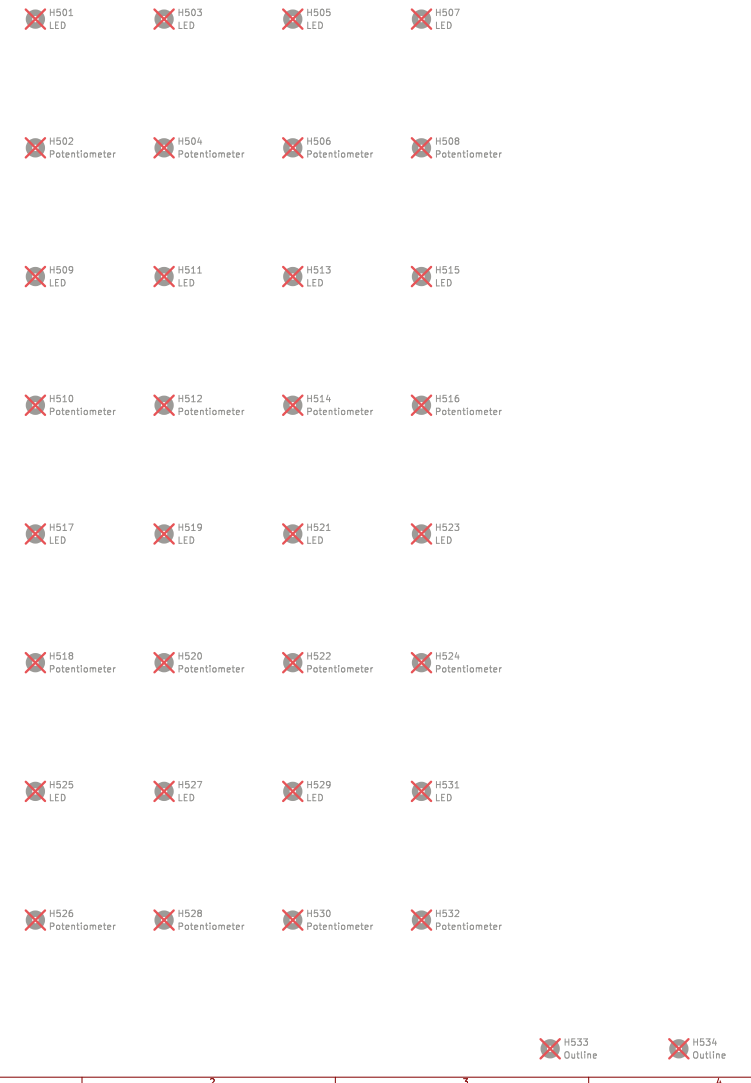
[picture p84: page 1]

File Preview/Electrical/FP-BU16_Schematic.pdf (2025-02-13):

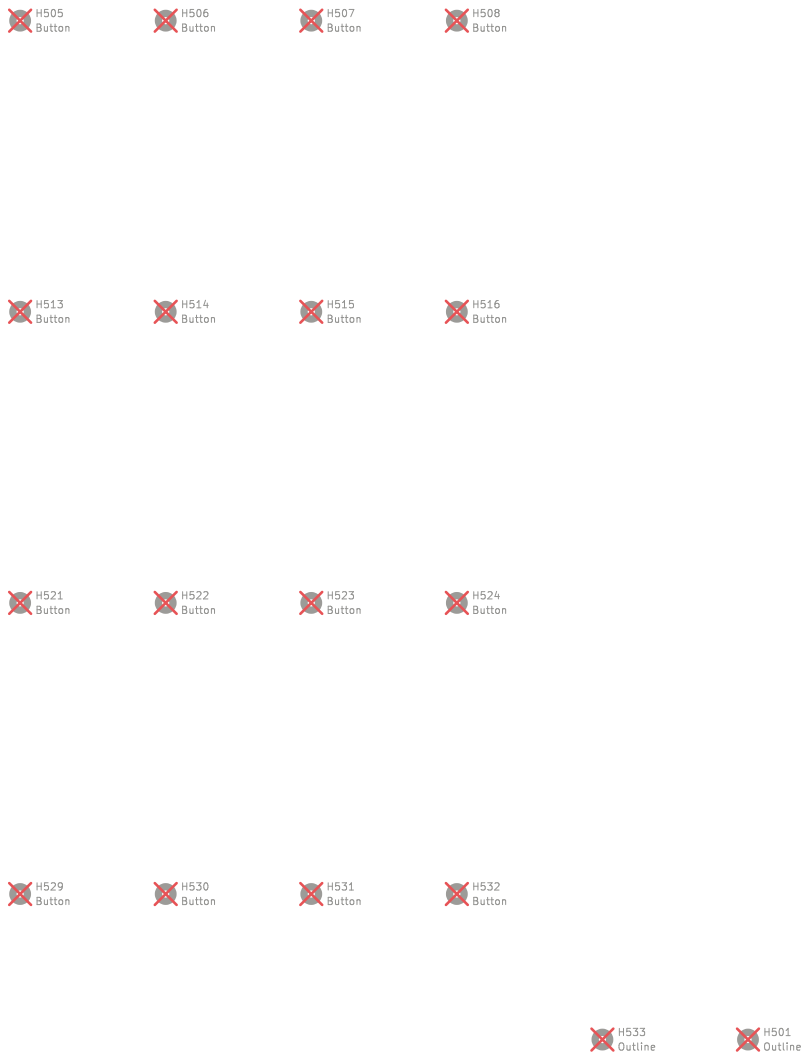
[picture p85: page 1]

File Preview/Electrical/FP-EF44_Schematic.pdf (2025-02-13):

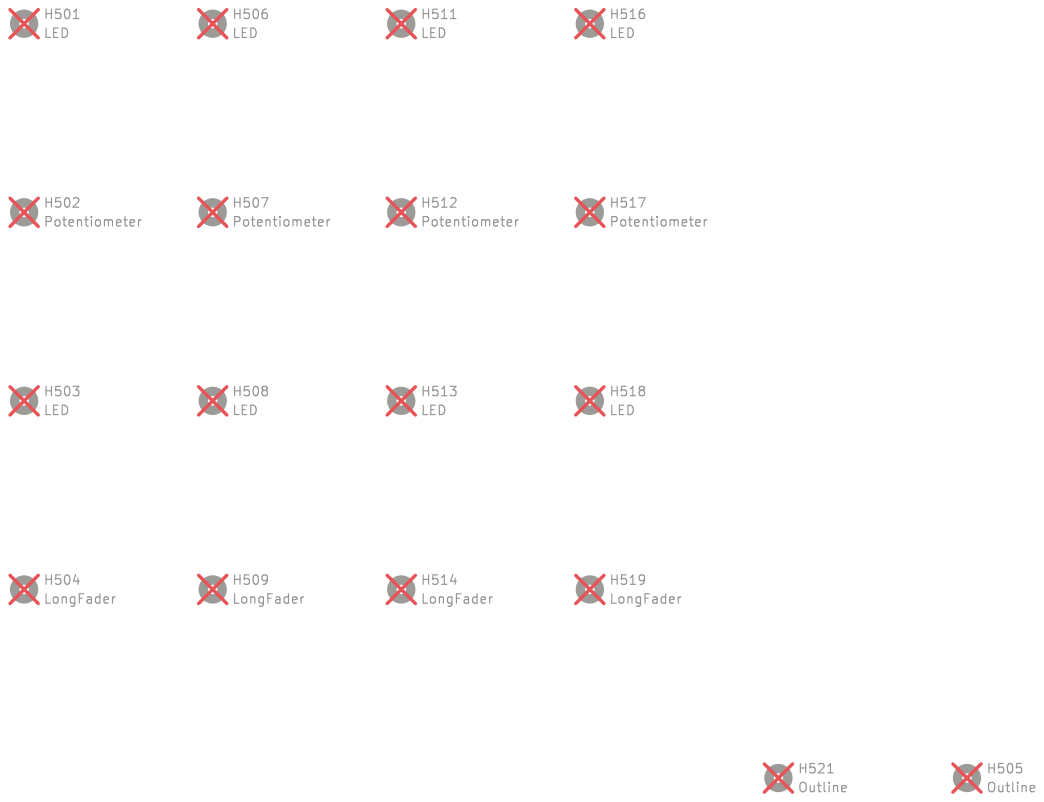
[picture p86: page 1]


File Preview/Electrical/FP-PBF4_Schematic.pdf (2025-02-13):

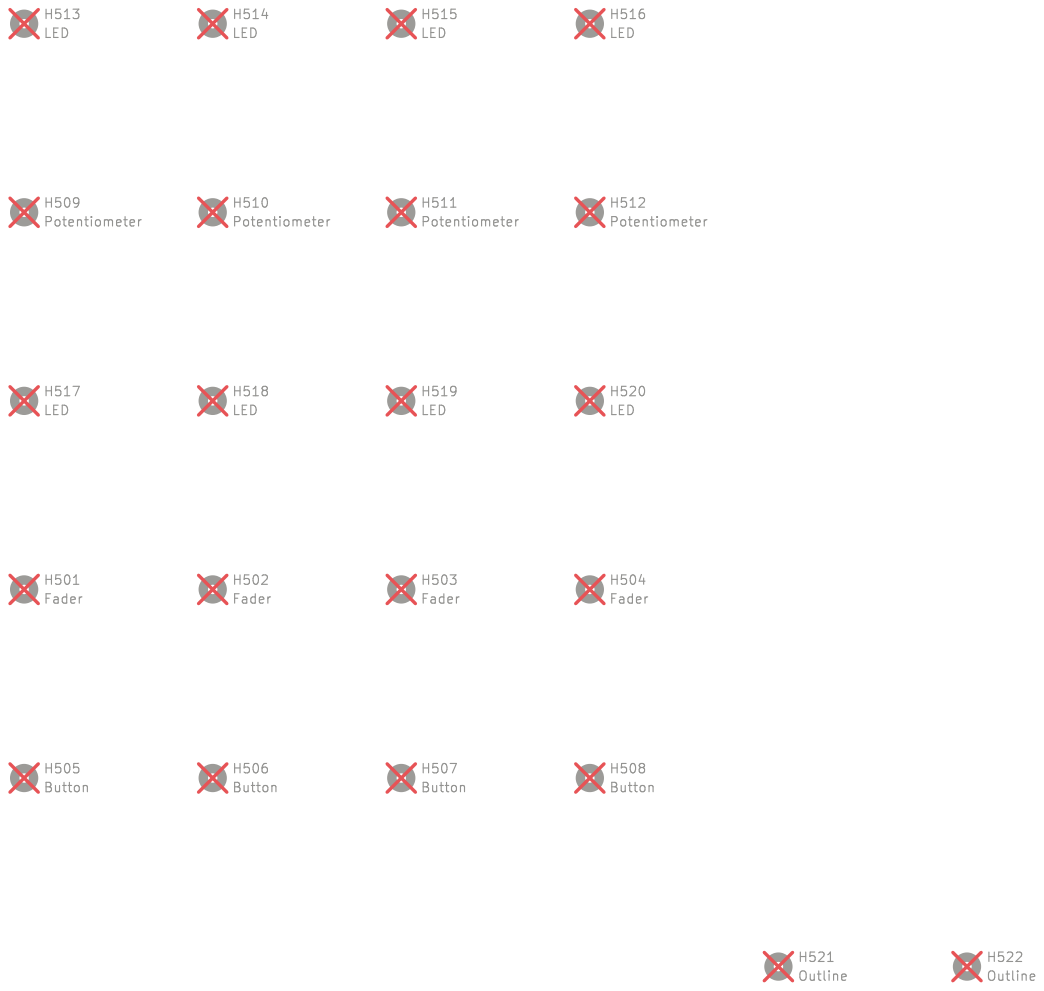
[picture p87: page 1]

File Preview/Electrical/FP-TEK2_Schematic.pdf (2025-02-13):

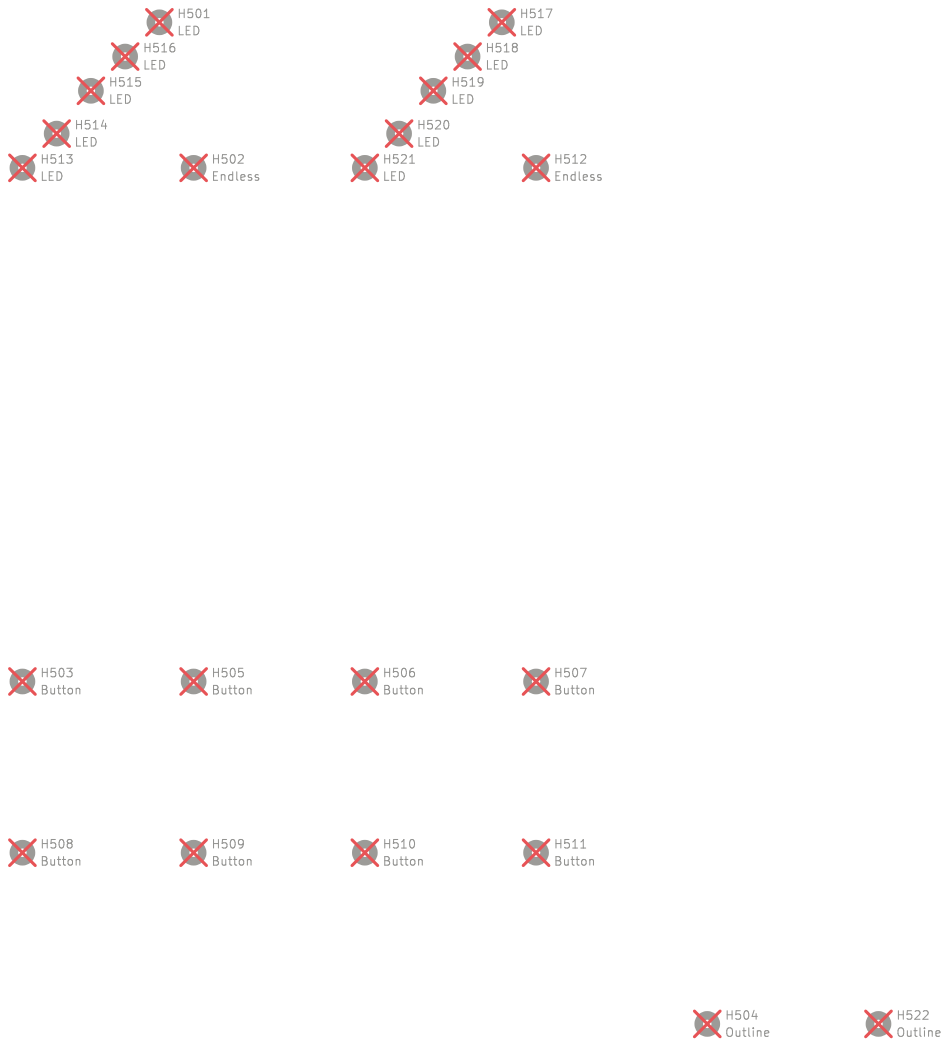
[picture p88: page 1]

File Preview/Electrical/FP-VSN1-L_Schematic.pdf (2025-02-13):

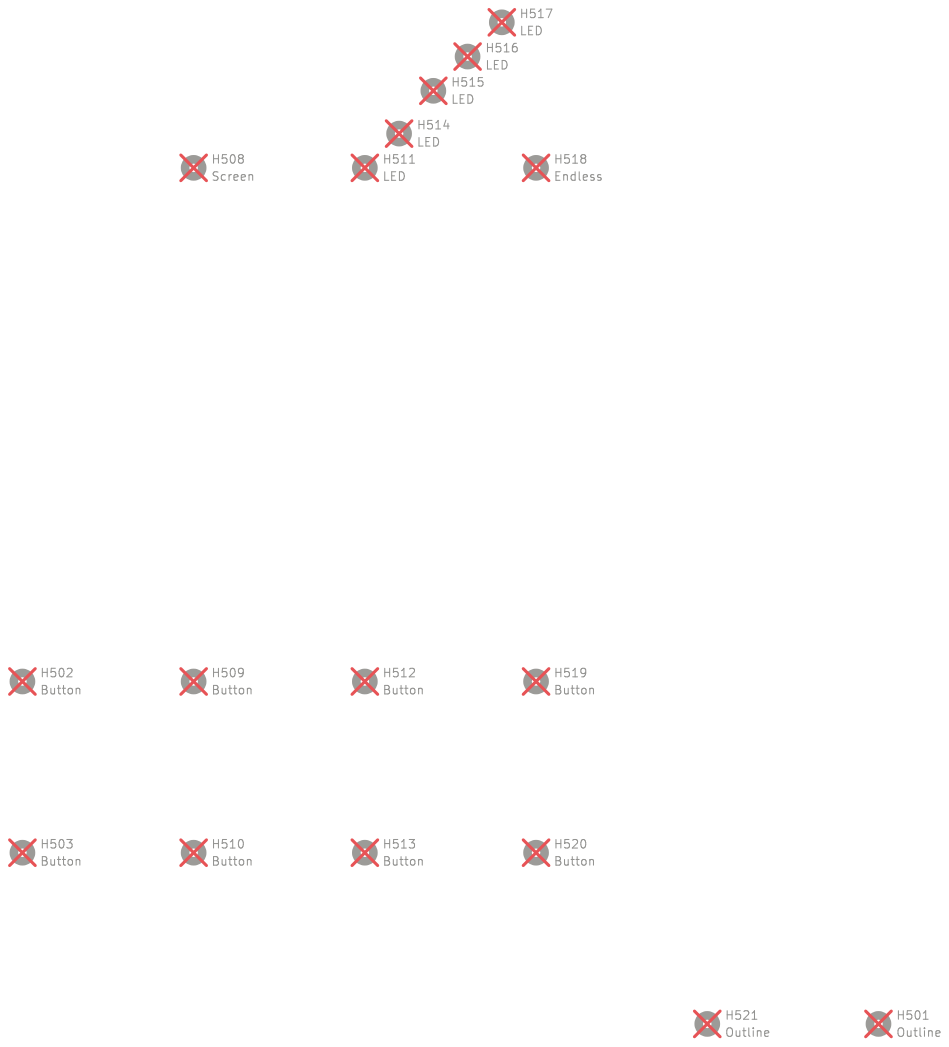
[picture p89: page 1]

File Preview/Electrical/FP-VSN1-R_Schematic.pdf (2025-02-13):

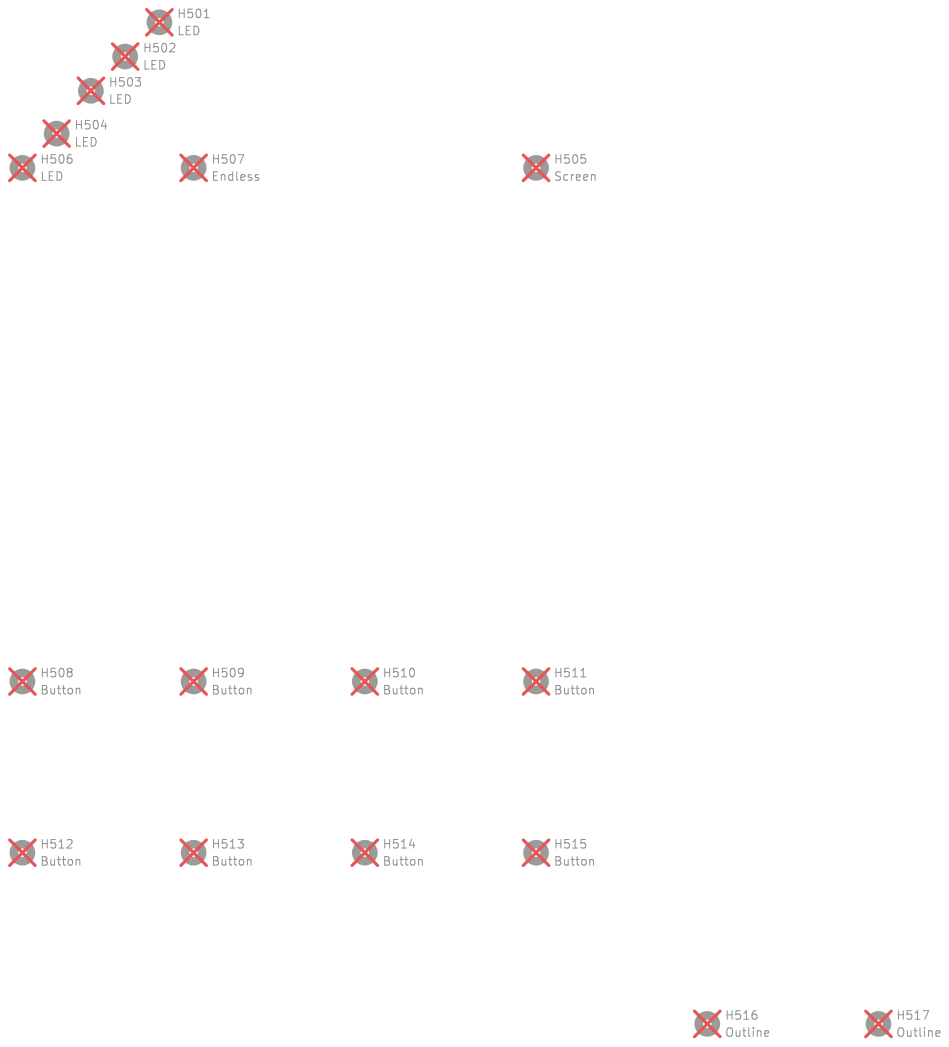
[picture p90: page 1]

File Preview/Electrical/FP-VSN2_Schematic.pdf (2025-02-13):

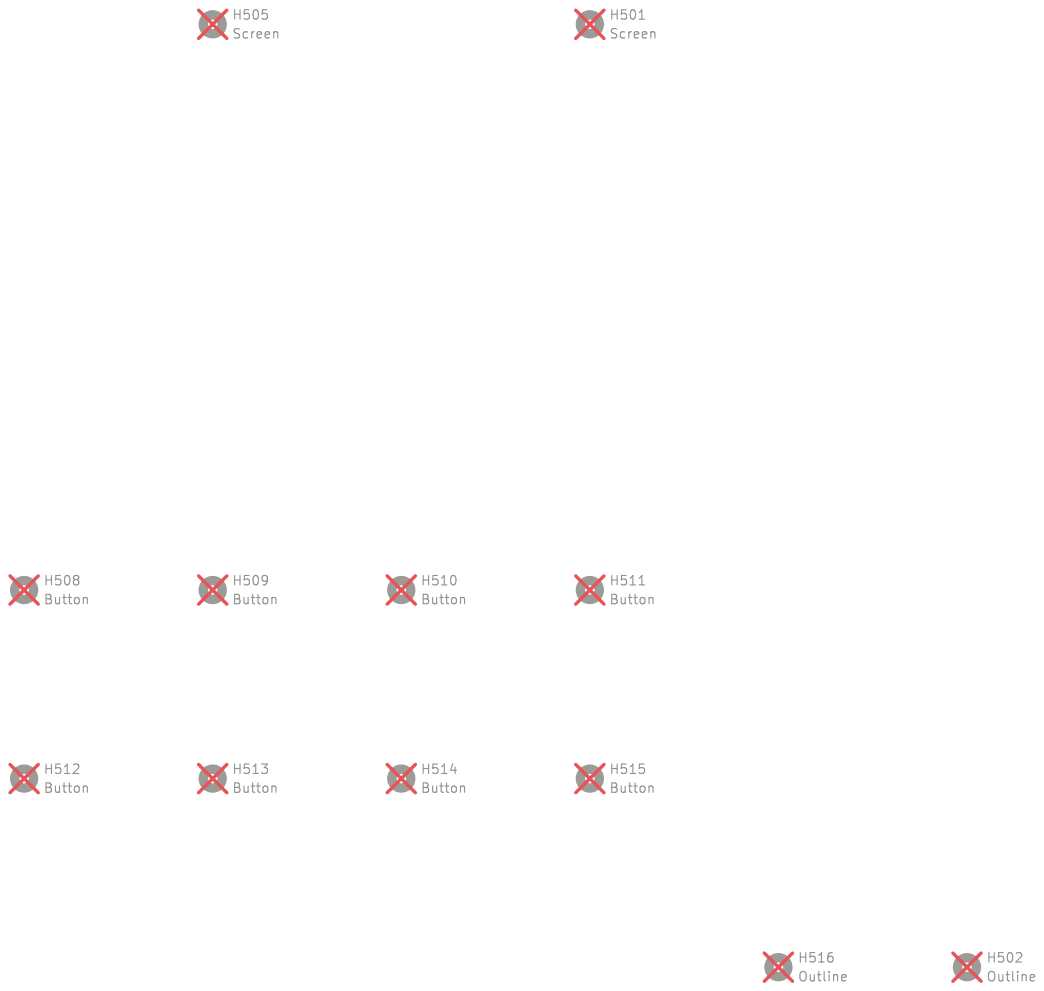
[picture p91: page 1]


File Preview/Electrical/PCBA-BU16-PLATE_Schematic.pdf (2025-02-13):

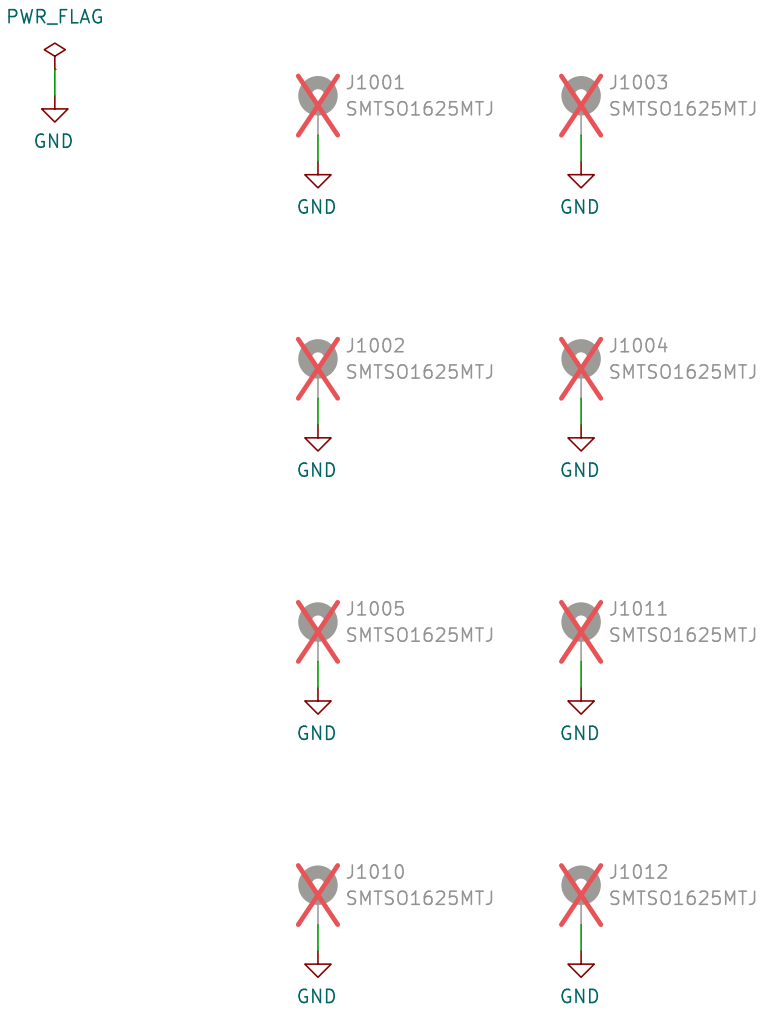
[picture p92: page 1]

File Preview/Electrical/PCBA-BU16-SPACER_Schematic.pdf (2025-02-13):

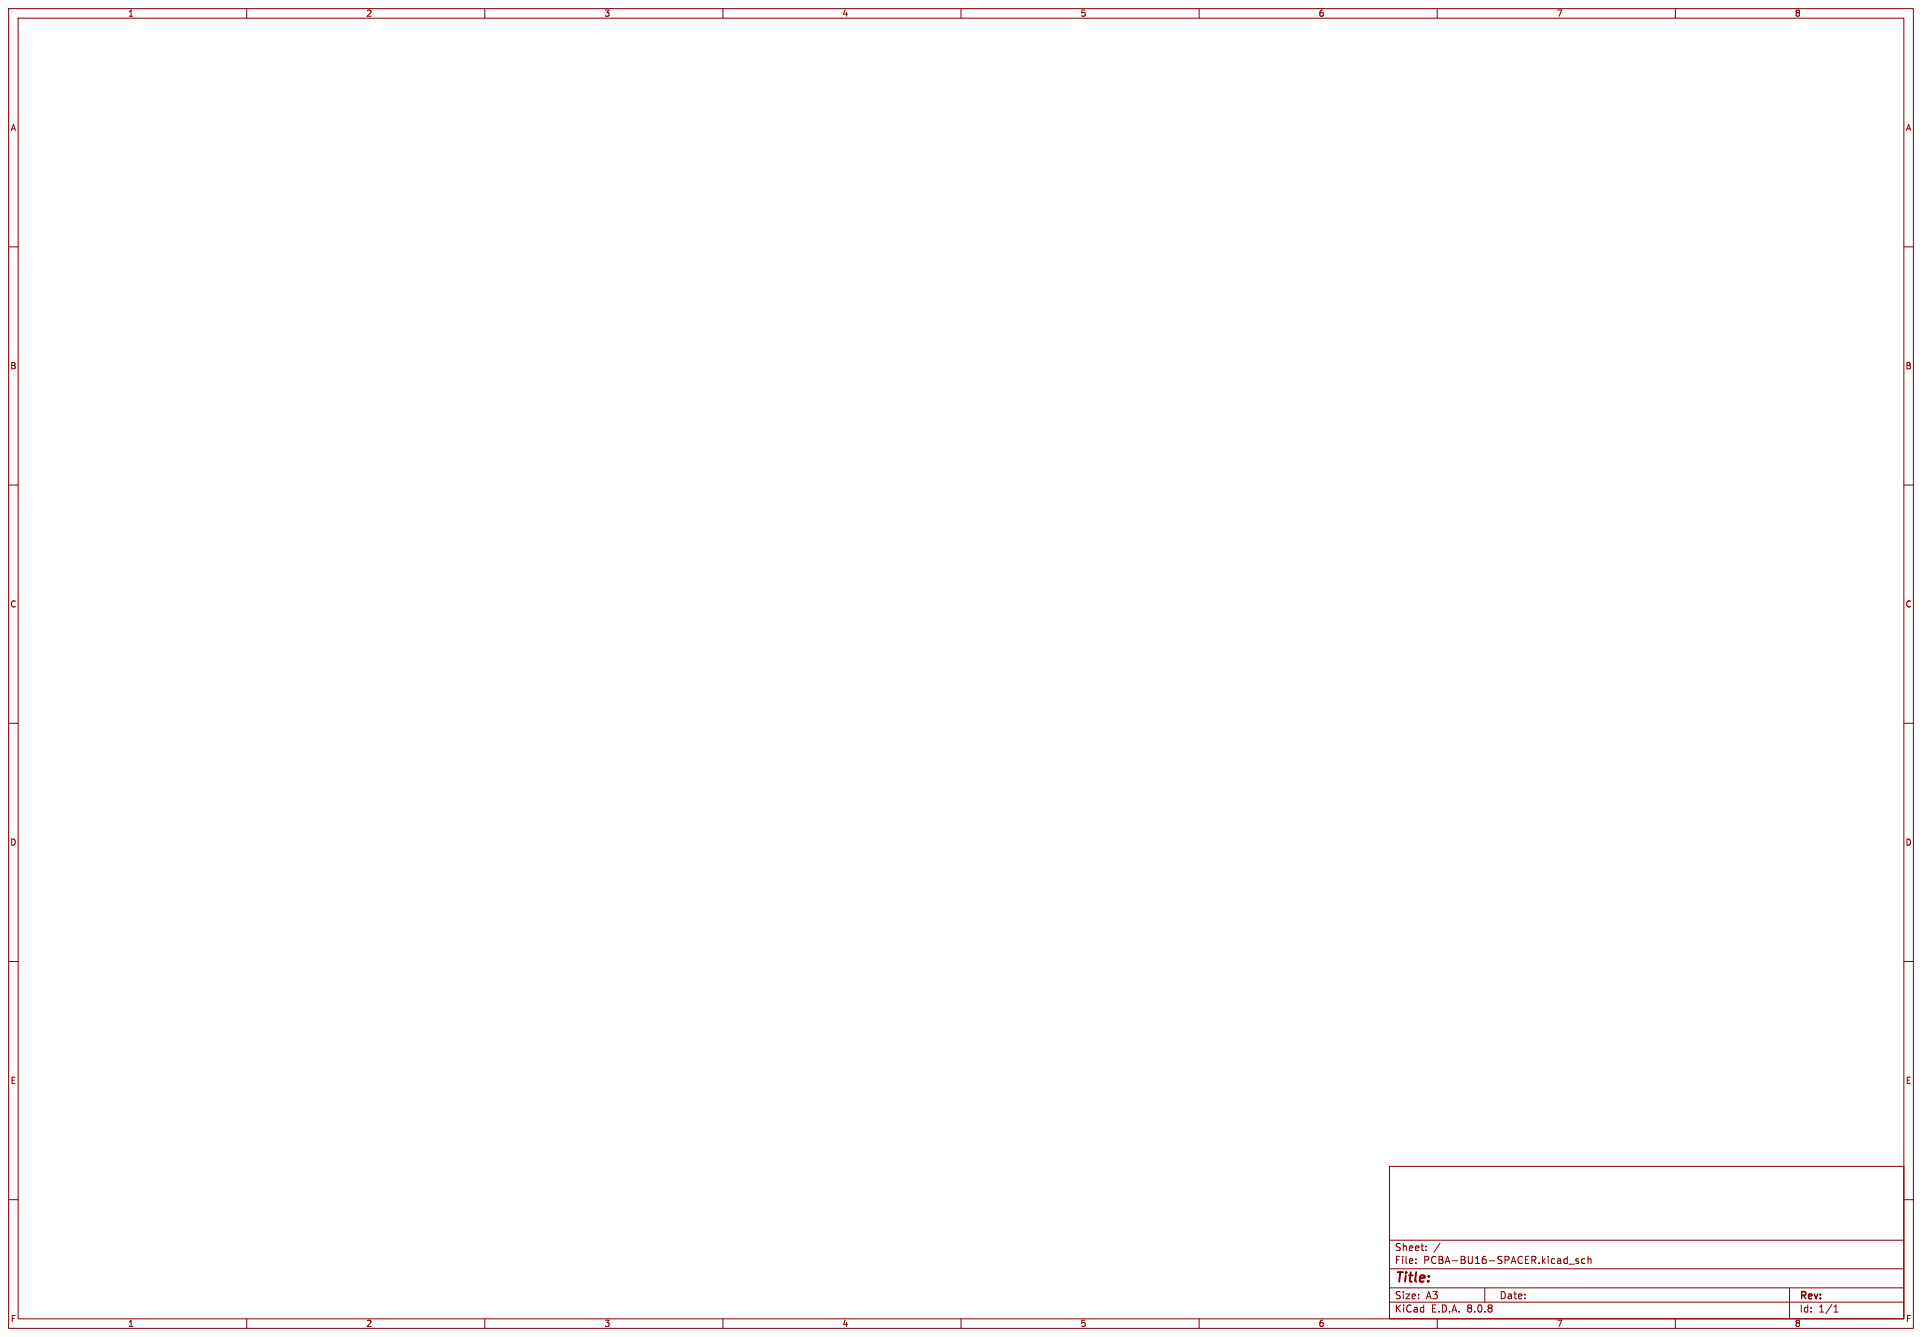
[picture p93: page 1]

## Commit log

2023-11-29 Build: (31bbaf3) SUKU test
    [BU16.step, Base.step, EF44.step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]
2023-11-29 SUKU delete files that were generated into wrong location
    [BU16.step, Base.step, EF44.step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]
2023-11-29 Build: (fff25d3) SUKU preview subfolder added
    [BU16.step, Base.step, EF44.step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]
2023-11-29 SUKU Delete Preview directory
    [BU16.step, Base.step, EF44.step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]
2023-11-29 Build: (6e164f1) SUKU folder updated
    [BU16.step, Base.step, EF44.step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]
2023-11-29 Build: (4634024) SUKU update Gui added
    [BU16.step, Base.step, EF44.step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]
2023-11-29 Build: (3713371) SUKU magnet drawing updated
    [MAGNET-D3x13.step, MAGNET-D3x13.stl, MAGNET-SQ3.step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]
2023-11-29 Build: (140534e) SUKU square magnet drawing updated
    [MAGNET-D3x13.step, MAGNET-SQ3.step]
2023-11-29 Build: (08b1d51) SUKU templates updated
    [MAGNET-D3x13.step, MAGNET-SQ3.step]
2023-11-29 Build: (3203f21) SUKU magnet sync
    [MAGNET-D3x13.step, MAGNET-SQ3.step]
2023-11-29 Build: (487493b) SUKU png generation fixed
    [MAGNET-D3x13.step, MAGNET-SQ3.step]
2023-11-29 Build: (8dfd948) SUKU test drawing added
    [MAGNET-D3x13.step, MAGNET-SQ3.step]
2023-11-29 Build: (561f9d6) SUKU template deleted
    [MAGNET-D3x13.step]
2023-11-29 Build: (f5e34db) SUKU test
    [MAGNET-D3x13.step, MAGNET-SQ3.step]
2023-11-29 Build: (704fa01) SUKU template readded
    [MAGNET-D3x13.step, MAGNET-SQ3.step]
2023-11-29 Build: (978efdf) SUKU page reduced to A4_TD
    [MAGNET-D3x13.step, MAGNET-SQ3.step]
2023-12-03 Build: (2bab9eb) Merge branch 'master' of https://github.com/intechstudio/grid-hardware
    [PLASTIC-BUSHING-POT.step, PLASTIC-BUSHING-POT.stl, PLASTIC-BUSHING-POT_Printed.step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]
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2023-12-05 Build: (b0ab46d) Merge branch 'master' of https://github.com/intechstudio/grid-hardware
    [MAGNET-D3x13.step, MAGNET-SQ3.step]
2023-12-05 Build: (5dab1dd) SUKU 8mm screw added to workflow
    [SCREW-M1.6x8.step]
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2023-12-05 Build: (da1e019) SUKU timeout added
    [SCREW-M1.6x16.step]
2023-12-05 Build: (f8336ee) SUKU paths fixed
    [INSERT-M1.6x2.5x3.step]
2023-12-05 Build: (19d351b) SUKU both screws single workflow
    [SCREW-M1.6x16.step, SCREW-M1.6x8.step]
2023-12-05 Build: (a3bbef9) SUKU combined insert workflow
    [INSERT-M1.6x2.5x3.step]
2023-12-05 Build: (f88a8d6) Merge branch 'master' of https://github.com/intechstudio/grid-hardware
    [INSERT-M1.6x2.5x3.step, INSERT-M1.6x2.5x4.step]
2023-12-05 Build: (158c99b) SUKU merge
    [INSERT-M1.6x2.5x3.step, INSERT-M1.6x2.5x4.step]
2023-12-05 Build: (7f0d65c) SUKU bushing and spacer updated
    [PLASTIC-BUSHING-POT.step, PLASTIC-BUSHING-POT.stl, PLASTIC-BUSHING-POT_Printed.step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]
2023-12-05 Build: (ee4a483) SUKU path updated
    [PLASTIC-SPACER.step, PLASTIC-SPACER.stl, PLASTIC-SPACER_Printed.step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]
2023-12-05 Build: (eea2a11) SUKU step to stl script test
    [BU16.step, Base.step, EF44.step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]
2023-12-05 Build: (210babf) SUKU canvas workflow added
    [BU16.step, Base.step, EF44.step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]
2023-12-05 Build: (b2194b8) SUKU sync
    [BU16.step, Base.step, EF44.step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]
2023-12-06 Build: (4a6806e) SUKU canvas full export to preview branch
    [BU16.step, Base.step, EF44.step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]
2023-12-06 Build: (6ecf0bf) SUKU file name fixed
    [PLASTIC_HOUSING.step, PLASTIC_HOUSING.stl, PLASTIC_MAGNET_CLIP.step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]
2023-12-06 Build: (53291ee) SUKU files renamed
    [PLASTIC-HOUSING.step, PLASTIC-HOUSING.stl, PLASTIC-MAGNET-CLIP.step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]
2023-12-06 Build: (93f2309) SUKU result zip name replaced
    [PLASTIC-BUSHING-POT.step, PLASTIC-BUSHING-POT_Printed.step]
2023-12-06 Build: (38ee06e) SUKU env changed
    [PLASTIC-BUSHING-POT.step, PLASTIC-BUSHING-POT_Printed.step]
2023-12-06 Build: (8c4d3ce) SUKU name variable added
    [BU16.step, Base.step, EF44.step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]
2023-12-06 Build: (e60f45f) SUKU screwsinserts workflow combined
    [INSERT-M1.6x2.5x3.step, INSERT-M1.6x2.5x4.step, SCREW-M1.6x16.step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]
2023-12-06 Build: (692ffca) SUKU fix
    [INTERFACE-bom.csv, INTERFACE-both_pos_fixed.csv]
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2023-12-06 Build: (b21ffba) BU16 drawing created
    [BU16.step, Base.step, EF44.step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]
2023-12-06 Build: (4499dc1) PBF4 drawing created
    [BU16.step, Base.step, EF44.step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]
2023-12-07 Build: (1ad42ea) SUKU substitutions fixed
    [EF44-bom.csv, EF44-both_pos_fixed.csv]
2023-12-07 Build: (e01c75a) SUKU erc errors fixed
    [EN16-bom.csv, EN16-both_pos_fixed.csv]
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2023-12-07 Build: (db6f41b) KLD frontpanel drawings done
    [Base.step, PBF4.step, XY.step]
2023-12-07 Build: (4647d84) KLD RUBBER-FOOT part and drawing
    [RUBBER-FOOT.step, RUBBER-FOOT.stl]
2023-12-07 Build: (65d7a60) SUKU recursive flag added
    [TEK2-bom.csv, TEK2-both_pos_fixed.csv]
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2023-12-07 Build: (ff8f0a9) SUKU pcb preview width reduced
    [BU16.step, BU16.stl, Base.step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]
2023-12-08 Build: (806a60b) KLD drawing name change
    [RUBBER-FOOT.step]
2023-12-08 Build: (d35d3e3) SUKU yaml mixup fixed
    [Base.step, PBF4.step, XY.step]
2023-12-08 SUKU remove
    [BU16.step, BU16.stl, Base.step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]
2023-12-08 SUKU electrical cleanup
    [EF44-bom.csv, EF44-both_pos_fixed.csv, EN16-bom.csv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]
2023-12-08 BOT electrical_boards f71b038b8bf8f8c16c5e7c93678fac3e35661dbe
    [PCBA-EF44-bom.csv, PCBA-EF44-both_pos_fixed.csv, PCBA-EN16-bom.csv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]
2023-12-08 SUKU misplaced files removed
    [PCBA-EF44-bom.csv, PCBA-EF44-both_pos_fixed.csv, PCBA-EN16-bom.csv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]
2023-12-08 BOT electrical_boards f74464fcea2e7e74343f0fded2d25ff7deaf7352
    [PCBA-EF44-bom.csv, PCBA-EF44-both_pos_fixed.csv, PCBA-EN16-bom.csv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]
2023-12-08 Build: (f5b19e6) KLD assembly created_grid weigth created
    [PLASTIC-HOUSING.step, PLASTIC-MAGNET-CLIP.step, PLASTIC-MAGNET-COVER.step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]
2023-12-11 Build: (ebdacfc) SUKU files shuffled, matric mechanical workflow proto added
    [INSERT-M1.6x2.5x3.step, INSERT-M1.6x2.5x4.step]
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2023-12-15 SUKU mechanical files removed
    [BU16.step, BU16.stl, Base.step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]
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
